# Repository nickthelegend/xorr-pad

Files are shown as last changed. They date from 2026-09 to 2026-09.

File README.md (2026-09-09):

# xorr-pad

**An AI agent that trades on your desk.**

<div align="center">
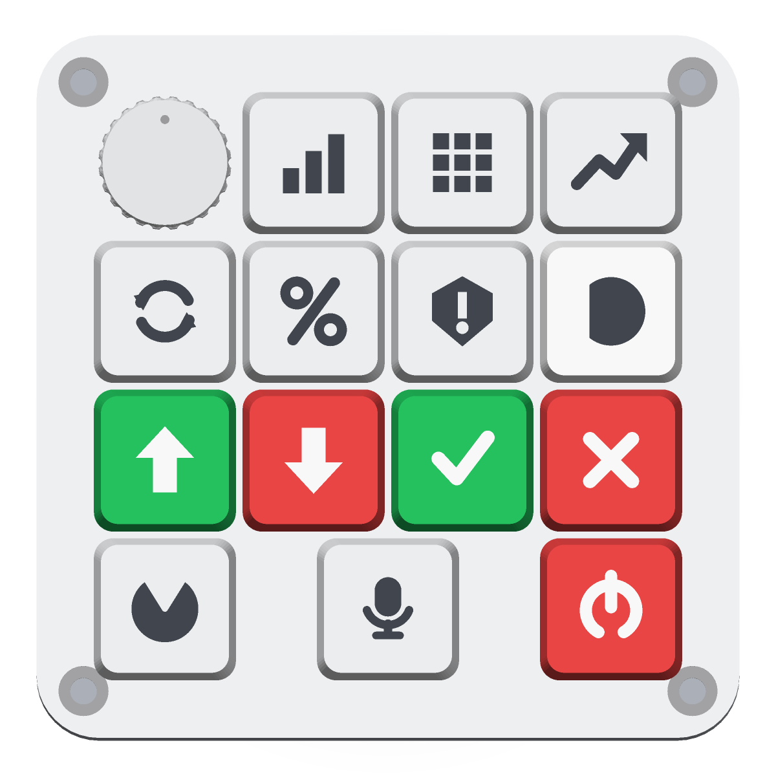
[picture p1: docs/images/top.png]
The xorr-pad deck — six agents, buy/sell, yes/no, Base, mic and a kill key

</div>

A physical deck that runs an autonomous agent on **Base**, and **remembers** —
your risk limits, the positions you hold, and every rule it learned from your
yes/no — through [Sibyl Memory](https://github.com/Sibyl-Labs/Sibyl-Memory).

It trades **four asset classes on Base**, and the strategies it runs are ported
from [xorr](https://github.com/nickthelegend/xorr)'s measured-edge book — built
from forward returns measured on both halves of two years, not from a thesis.

Delete the memory and it trades blind. That is not a slogan; it is
[a test](desktop/test/loadbearing.test.mjs) that runs the same signals with and
without the store and asserts the verdicts diverge.

## What it trades

Every market was picked by measurement, not by taste: quote a real Uniswap V3
pool at $50 and at $500 and compare the two prices. If the bigger order does not
price within 2% of the smaller one, it is not tradeable and it is not listed.

| market | class | pool | a $500 order moves it |
|---|---|---|---|
| **ETH** | crypto | 0.01% tier | 0.01% |
| **cbBTC** | crypto | 0.05% | 0.00% |
| **EURC** | **forex** — a real EUR/USD position on Base | 0.05% | 0.01% |
| **AERO** | defi | 0.05% | 0.10% |
| **MORPHO** | defi | 1% | 0.03% |
| **VIRTUAL** | ai agents (Virtuals) | 0.3% | 0.01% |

Delisted by the same measurement: **DEGEN** (a $500 order moves the pool
**239.7%**), BRETT (52%), cbETH (8.3%), and wstETH/WELL/ONDO (no pool at all).
DEGEN was in the pad's allowlist until this check existed — memory says what you
are *allowed* to trade; only the pool says what you can trade without destroying
yourself on the way in. `swap()` refuses before signing when the two disagree.

**On stocks:** this changed under the project. Coinbase put tokenized equities
live natively on Base on **24 August 2026** — each backed 1:1 by a share held at
Alpaca, carrying dividends and voting rights. Ten of them are listed in
[`stocks.mjs`](desktop/main/stocks.mjs), every one verified against real mainnet
by reading `symbol()` and `decimals()` back off the chain, with $599k–$2.23M of
measured depth apiece: NVDAc, GOOGLc, AAPLc, METAc, AMZNc, MSFTc, SNDKc, SPCXc,
TSLAc, MSTRc.

**The pad cannot trade them yet, and says so precisely rather than failing
vaguely.** Two separate reasons, never conflated:

1. They are **B20 tokens — implemented by the Base node, not as EVM bytecode**.
   `eth_getCode` returns a single byte, `0xef`. anvil forks *state*, and there is
   no state here to fork, so on a fork every call to one of these reverts with
   `OpcodeNotFound`. Measured the same day, same address: real mainnet answers
   `symbol() -> "NVDAc"`, the fork throws. **Equities cannot be demonstrated on a
   fork at any block** — they need `CHAIN_MODE=mainnet` and real money.
2. Their depth is on a concentrated-liquidity pool this build cannot route to
   (a custom factory, `0xf8f2…61Ef`, plus Uniswap v4). The Uniswap V3 pair this
   codebase *can* reach holds $11k — too thin to use. That needs an aggregator,
   which is Phase 2 of [`PLAN.md`](PLAN.md).

So EURC remains the non-crypto market that actually fills today. The equities are
listed, priced by the chain, and refused with the reason — which is the honest
state of a market that went live three weeks ago.

## The book — six measured strategies

Ported from xorr's `backend/strategies`, thresholds and holding periods intact:

| strategy | condition | measured (in-sample / held-out) |
|---|---|---|
| `deep_stretch_reversion` | ≥6% below the 50-bar mean | **+2.351% / +1.249%**, t=7.49, n=1353 |
| `oversold_exhaustion` | RSI < 25 | +0.577% / +0.393%, t=3.81, n=1652 |
| `stretch_capitulation` | ≥3% below the mean on 1.8× volume | two measured effects agreeing |
| `stretch_oversold_confluence` | ≥3% below **and** RSI < 32 | the intersection of the two strongest |
| `volume_thrust` | top-decile up move on 2.5× volume | +0.170% / +0.101%, t=1.84, n=1264 |
| `mr_band_fade` | 2σ below a 20-bar mean, in chop only | the ungated control that survived |

Two gates are shared, as in xorr: dip buying is switched **off** entirely while
BTC is below its 200-day mean (measured +0.946%/trade above it, −0.022% below),
and nothing is bought while it is still making lows.

**Not ported on purpose:** the ~45 inherited "fade the liquidation flush"
strategies. xorr's own gauntlet found almost all of them fail out-of-sample, and
shipping known-failing strategies to make a bigger number would be dishonest.

**And the honest part:** none of this has been shown to make money. xorr's live
book was +$4.32 gross and −$23.07 net over its first 30 trades, the entire loss
being fees. These are real, measured, too-small-to-pay-for-execution edges. The
pad runs them because they are real and explainable, not because they print.

## The deck

| | c0 | c1 | c2 | c3 |
|---|---|---|---|---|
| **r0** | 🎛 size knob | DCA | GRID | MOMENTUM |
| **r1** | REBALANCE | YIELD | RISK | ⬜ BASE |
| **r2** | 🟩 BUY | 🟥 SELL | 🟩 YES | 🟥 NO |
| **r3** | PORTFOLIO | 🎤 MIC | | 🟥 KILL |

Press an agent to take the baton, BUY/SELL to propose, YES/NO to answer — and
every yes/no teaches it. Hold MIC on the pad, or press MIC on screen to start
and again to send, and just say *"buy fifty dollars of ETH"*. A spoken order
goes through the same gate as any other: it arrives as a decision waiting on a
✓, never as a fill.

## Run it

```bash
cd desktop && npm install

# 1. a Base mainnet fork — real contracts and liquidity, no real money
npm run fork

# 2. pull the pools and balances into the fork's cache, once (~2 min)
npm run warm

# 3. the desk app (hosts the backend the pad talks to)
CHAIN_MODE=fork PAD_TOKEN=xorrpad-dev npm start
```

Step 2 is not optional theatre. anvil fetches state from the upstream lazily,
the public Base RPC rate-limits hard, and the first read of a pool can take
**55 seconds** — in the middle of a trade, which looks like the app hanging.
Warming pulls it all in once; after that every read is local and answers in
single-digit milliseconds.

It prints the LAN URL to type into the pad's captive portal. Point a browser at
`http://localhost:8080/?token=xorrpad-dev` if you'd rather drive it by hand —
**every pad key is clickable**, which matters because hand-soldered pads have
dead switches.

Prove the memory claim:

```bash
node desktop/test/loadbearing.test.mjs
```

## How a trade happens

```
memory ──▶ market ──▶ six agents ──▶ decide() ──▶ Uniswap on Base ──▶ journal
recall     real        propose        the gate      real signed tx     writeback
```

`decide()` is built only from what Sibyl remembers: it clamps to your cap,
vetoes anything matching a rule you accepted, refuses to sell a position it
cannot see, and subtracts today's spend from the journal.

**On routing, and on 1inch.** Two routers are built. **Uniswap V3** is a direct
`exactInputSingle` and needs nothing but an RPC. **KyberSwap** is a real DEX
aggregator that needs **no API key and no signup** — it splits across venues and
reaches the concentrated-liquidity pools a direct V3 call cannot, which is the
only way this project can price the tokenized equities at all.

Every fill quotes both and takes the better one, keeping the loser's quote on
the fill so the choice is auditable rather than trusted. Measured on real
quotes, KyberSwap led by 0.42% / 0.023% / 0.082% on AERO / ETH / cbBTC. If the
aggregator fails — it refuses some senders, and it quotes live mainnet while a
fork drifts away from it — the fill falls back to the direct pool and *says so*
on the card.

**1inch is not used.** The name covers three things: an aggregator API, a
self-custody wallet app, and a token. None of them are here. There is no 1inch
call in the codebase, no wallet app and no WalletConnect — the agent holds a key
from the environment and signs with viem, because a pad that needs a human to
approve a wallet popup for every fill is not an agent. 1inch's API needs KYC;
KyberSwap did the job without it.

The route a fill reports is read back off the mined receipt's `to`, so it can
never claim a venue it did not use. Setting `ONEINCH_API_KEY` changes nothing,
and the suite asserts that.

## What's in here

| Path | What it is |
|---|---|
| `desktop/memory/sibyl_bridge.py` | the memory, over stdio JSON (Sibyl is Python-only) |
| `desktop/main/memory.mjs` | Node client — `recallBrief()` and the journal |
| `desktop/main/agents.mjs` | dca · grid · momentum · rebalance · yield · risk |
| `desktop/main/decide.mjs` | the gate where memory changes the trade |
| `desktop/main/dex.mjs` | quotes and real swaps on Base |
| `desktop/main/reflect.mjs` | mines your yes/no history into rules you accept |
| `desktop/main/voice.mjs` | Deepgram speech + a brain that has read memory |
| `firmware/` | the ESP32-S3 sketch, and `keytest` for wiring |
| `cad/` | the enclosure, parametric — `python assembly.py` rebuilds every STL |

## Hardware

ESP32-S3, 14 MX switches, INMP441 mic, MAX98357A amp + speaker. Wiring and pin
map in [`firmware/README.md`](firmware/README.md); dimensions in
[`SPEC.md`](SPEC.md). Caps print in three filaments —
`exports/print/xorr-pad-keycaps.3mf` opens straight in Bambu Studio.

`firmware/keytest` maps a hand-soldered matrix for you: it names each key, you
press it, and it prints a paste-ready `KEYMAP` — plus it beeps per key so you
can hear a dead switch.

## Status

- [x] enclosure, caps, 3MF
- [x] Sibyl memory + the load-bearing proof
- [x] Base fork, real Uniswap fills
- [x] six agents, `decide()`, kill switch
- [x] desk app, voice
- [x] firmware rewritten for xorr-pad — compiles for the S3, backend contract
      covered by the suite; **not yet flashed** (no board on this machine)
- [ ] finish the key sweep (one dead switch, row 3 unswept)
- [x] an aggregator route — **KyberSwap**, which needs no API key at all. It
      reaches the concentrated-liquidity venues a direct V3 call cannot, prices
      every tokenized equity, and every fill picks the better of the two routers
      and records the loser's quote
- [ ] trade the equities for real — the route exists; a B20 token cannot exist
      on a fork, so this needs mainnet
- [ ] Virtuals beyond trading VIRTUAL (no agent-registry integration)

MIT. See [`PLAN.md`](PLAN.md) for the full build plan and
[`SUBMISSION.md`](SUBMISSION.md) for the memory writeup.

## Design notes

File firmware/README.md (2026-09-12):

# xorr-pad — firmware

ESP32-S3 firmware for the trading pad. Take a market in hand, propose a trade,
confirm it with a physical ✓ — or hold the mic key and say it out loud. Wi-Fi
and the backend address are set once through a captive portal and remembered in
flash; **no recompile to change networks**.

Sketch: [`orchestrator_pad/orchestrator_pad.ino`](orchestrator_pad/orchestrator_pad.ino).

> **Nothing on this pad can move money on its own.** BUY and SELL raise a
> decision; only ✓ executes it, only while the backend says it is armed, and the
> same gate answers whether the key was pressed here or on screen. The firmware
> holds no opinion about limits, positions or what is armed — it asks.

## What it does

1. **Provision** — first boot (or hold the reset key at power-on) raises an
   access point, **`xorr-pad-setup`**. Join it; a captive page lists nearby
   networks and asks for the **backend URL** and a **pad token**. The URL is
   validated before it is saved — a pad that cheerfully stores `192.168.1.5`
   with no scheme boots into a state where nothing works and the portal has
   already closed.
2. **Connect** — it starts a telnet console, polls `GET /pad`, and speaks
   something true through the amp: whether it is armed, what is in hand, and
   whether the store has been wiped.
3. **Run** — keys drive the same backend the desk app drives. The status light
   is the backend's state, not the firmware's guess.

## The deck

```
  MOMENTUM   RISK       YIELD      DCA          ← who holds the baton
  ETH        cbBTC      AERO       VIRTUAL      ← what is in hand
  BUY        SELL       SCAN       PORTFOLIO    ← propose / run the book
  ✓ CONFIRM  ✗ REFUSE   MIC        KILL         ← answer / speak / stop
```

Every id is exactly what `POST /key` accepts. There is no translation table: if
an id is not real, the backend says so and the pad speaks the refusal.

**KILL is held, not tapped** — 600 ms. A brush against the key that stops all
trading is not acceptable.

**MIC is hold-to-talk.** The recording goes to `POST /voice` as raw 16 kHz mono
PCM; the spoken reply streams straight back to the amp. A spoken order lands as
a decision waiting on a ✓, exactly like a key press.

## The status light

| State | Light |
|---|---|
| Backend unreachable | dark blue, pulsing — the pad is alone |
| Trading stopped | hard red, steady |
| A decision waits on a ✓ | amber, breathing |
| Memory wiped | white, breathing — it will refuse anything but the smallest trade |
| Armed | the agent's own colour, dim and steady |

The order matters: the most dangerous state wins the light.

## Hardware & wiring

ESP32-S3-DevKitC-1 (**N16R8** — 16 MB flash / 8 MB PSRAM). No pot, no diodes.

<div align="center">
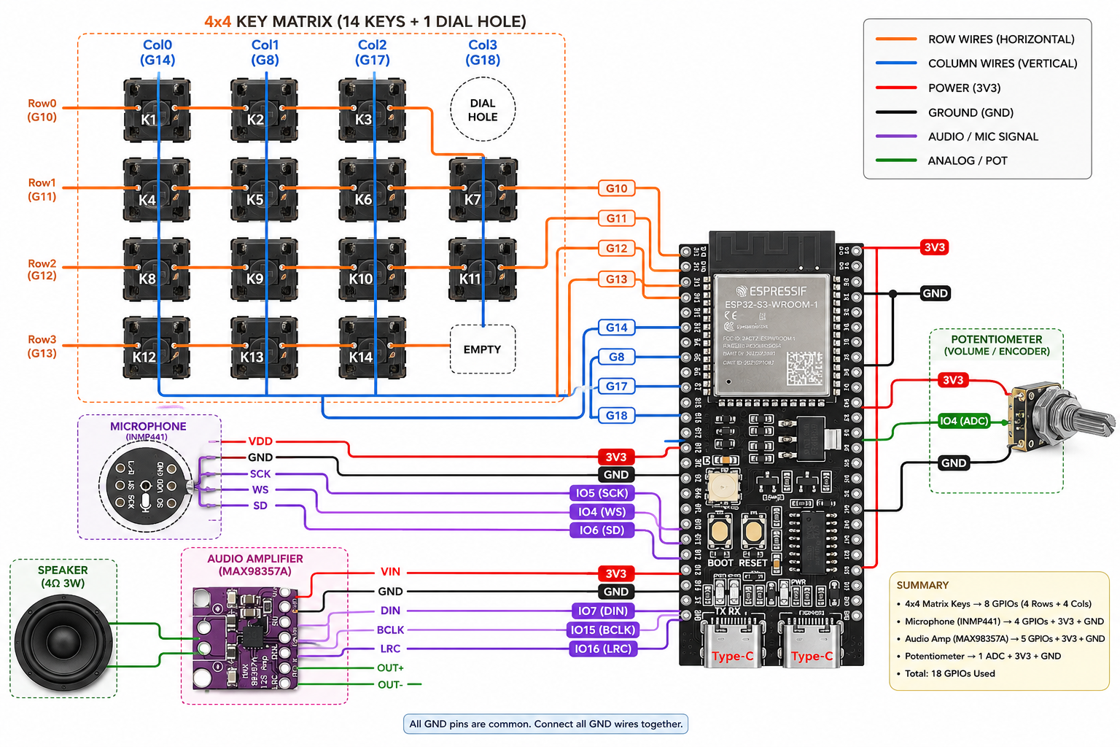
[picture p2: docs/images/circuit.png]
xorr-pad wiring diagram — 4×4 key matrix, INMP441 mic, MAX98357A amp + speaker, on an ESP32-S3-WROOM-1

</div>

The full wiring at a glance: the 4×4 matrix (rows `G10–G13`, columns
`G14/G8/G17/G18`) and the INMP441 mic and MAX98357A amp on I2S. The tables below
are the same thing, cell by cell — all grounds are common.

**Mic — INMP441 (I2S RX):** `VDD→3V3`, `GND→GND`, `L/R→GND`

| INMP441 | SCK | WS | SD |
|---|---|---|---|
| GPIO | **5** | **4** | **6** |

**Amp — MAX98357A (I2S TX):** `Vin→3V3`, `GND→GND`, `SD→3V3` (leave SD high to enable)

| MAX98357A | BCLK | LRC | DIN |
|---|---|---|---|
| GPIO | **15** | **16** | **7** |

**4×4 key matrix** (rows are `INPUT_PULLUP`, columns driven low one at a time —
no diodes needed):

| | Col0 | Col1 | Col2 | Col3 |
|---|---|---|---|---|
| **Rows →** | GPIO 14 | GPIO 8 | GPIO 17 | GPIO 18 |
| Row0 · GPIO 10 | **K1 mic** | K2 | K3 | — |
| Row1 · GPIO 11 | K4 | K5 | K6 | K7 |
| Row2 · GPIO 12 | K8 | K9 | K10 | K11 |
| Row3 · GPIO 13 | K12 | K13 | K14 | — |

**Status LED:** onboard WS2812 on **GPIO 48**.

**Display pod (optional):** a 2.8" ILI9341 320×240 SPI screen (LCDwiki MSP2807),
laid landscape, showing the market in hand — price, 24h move and a 48-hour chart
from `GET /pad/chart`. The enclosure is `exports/display-pod-28.stl` and
`exports/display-cap-28.stl` (`cad/part_display.py`); the print plate is
`exports/print/display-plate-28.3mf`. Touch is not used.

| Module pin | VCC | GND | CS | RESET | DC | SDI(MOSI) | SCK | LED |
|---|---|---|---|---|---|---|---|---|
| Goes to | 3V3 | GND | GPIO **1** | GPIO **42** | GPIO **41** | GPIO **40** | GPIO **39** | GPIO **2** |

Leave SDO(MISO) and the five touch pins (T_CLK, T_CS, T_DIN, T_DO, T_IRQ)
unconnected. At power-on the screen shows a test card — colour bars and an arrow
that should point up the slant. If it points down, type `rot 3` on the telnet
console to check, then set `TFT_ROTATION 3` in `config.h`; `screen` reports what
the display last drew. These pins avoid the octal PSRAM (35–37), USB (19/20),
UART0 (43/44) and the strapping pins (0, 3, 45, 46).

**2.4" UNO shield:** the pod fits it (`exports/display-pod-24.stl`), but this
firmware does not drive it. That shield is an **8-bit parallel** display — 12
pins for the LCD alone, and its resistive touch shares four of them — while the
pad's ESP32-S3 has 10 free. The SPI version of the same 2.4" ILI9341 panel (with
XPT2046 touch) fits the pin budget; the pod is parametric (`MODULES` in
`cad/part_display.py`), so another board is a few numbers.

All pins live in [`orchestrator_pad/config.h`](orchestrator_pad/config.h) — change
them there if your wiring differs.

The 12-second record buffer is 384 KB and **lives in PSRAM**, so PSRAM must be
enabled at build time. It is off in the default board config.

## Building

### From the command line

```bash
arduino-cli core install esp32:esp32
arduino-cli lib install WiFiManager
arduino-cli lib install "Adafruit ILI9341"

arduino-cli compile \
  --fqbn esp32:esp32:esp32s3:FlashSize=16M,PartitionScheme=app3M_fat9M_16MB,PSRAM=opi \
  firmware/orchestrator_pad
```

**Those board options are not optional.** With the bare `esp32:esp32:esp32s3`
default you get a 4 MB partition scheme — the binary lands at 90% of the
available app space — and **PSRAM disabled**, which means the record buffer
never allocates. With the options above it is 39% and the mic works.

To flash, add `--port <the pad's port>` and `upload` in place of `compile` —
`/dev/cu.usbserial-*` on the board's UART USB-C, where the Serial log also
comes out. Plugged into its native USB-C instead (`/dev/cu.usbmodem*`), add
`,CDCOnBoot=cdc` to the FQBN to get the log there. With more than one ESP32
connected, check the port is the pad's before uploading.

### From the Arduino IDE

**Libraries** (Library Manager):

- **WiFiManager** by *tzapu* — the captive portal.
- **Adafruit ILI9341** (pulls in Adafruit GFX) — the display pod.
- `ESP_I2S`, `WiFi`, `HTTPClient`, `Preferences` ship with the **arduino-esp32
  core 3.x** — nothing to install, but you do need core 3.x (Boards Manager →
  "esp32" by Espressif, ≥ 3.0).

**Board settings** (Tools menu) — the three starred ones are the same
constraints as the FQBN above:

- Board: **ESP32S3 Dev Module**
- ⭐ **PSRAM: `OPI PSRAM`** — the record buffer is `ps_malloc`'d; without this it
  fails to allocate and the mic won't record.
- ⭐ **USB CDC On Boot: `Enabled`** — so the Serial monitor works over USB-C.
- ⭐ **Partition Scheme: `Huge APP (3MB No OTA/1MB SPIFFS)`** — the TLS stack
  pushes the build to ~90 % of the *default* app partition (it fits, but
  barely). Huge APP drops it to ~38 %. Flash Size: `16MB`.

**Steps:**

1. Open [`orchestrator_pad/orchestrator_pad.ino`](orchestrator_pad/orchestrator_pad.ino).
2. Install WiFiManager, set the board options above, pick the port, **Upload**.
3. First boot: join the **`xorr-pad-setup`** Wi-Fi from your phone. If the portal
   doesn't pop up, browse to `http://192.168.4.1`.
4. Pick your Wi-Fi, enter the **backend URL** and **pad token** (below), save.
5. It joins, says what state the desk is in, and you're ready: **take a market,
   press BUY, confirm with ✓** — or hold **K1** and say it.

### Backend URL & token

One field decides where — and how — the pad reaches the backend; the **scheme
picks the transport**:

| You're… | Enter | Token |
|---|---|---|
| on the same Wi-Fi as the Mac | `http://<mac-lan-ip>:8080` (e.g. `http://192.168.1.20:8080`) | blank is fine on a trusted LAN |
| anywhere / the pad moves around | `https://<machine>.<tailnet>.ts.net` (Tailscale Funnel) | **required** — Funnel is public |

- **`http://…`** → plain connection. Use the Mac's **LAN IP**, *not* its
  `tailscale ip` (`100.x`) — a bare ESP32 can't route to a tailnet address.
- **`https://…ts.net`** → TLS, with the Let's Encrypt root pinned (the pad
  verifies the cert, so the token can't be MITM'd). Set the same `PAD_TOKEN` on
  the backend, which lives in [`desktop/`](../desktop).

A URL that cannot work is refused at the portal rather than saved — see
`Provision::validUrl`. Change either later without reflashing: `reset-wifi` over
telnet (or hold **K1** at power-on) re-opens the portal.

## Telnet console

The S3's USB-CDC serial can be flaky, so the pad mirrors its logs to a telnet
server and takes commands back — no cable needed:

```
telnet <pad-ip>
```

| Command | What it does |
|---|---|
| `status` | Wi-Fi, heap, backend, and the pad's view of the backend |
| `pad` | one raw `GET /pad` poll, printed |
| `map` | the key map as currently compiled |
| `key <id>` | press any key id by hand — the same route the caps use |
| `say <text>` | speak a line through the amp |
| `talk` | hands-free record for 4 s and send |
| `url <u>` / `token <t>` | repoint the backend without re-provisioning Wi-Fi |
| `reset-wifi` | forget the network and reopen the portal |

`say hello` and `talk` are the fastest way to prove the audio path end to end.

## Mapping a scrambled matrix

[`keytest/`](keytest) is a standalone sketch — flash it *instead of* the main
firmware. It has two modes over the serial monitor at 115200 baud:

- **MAP** names a key, you press it, and it records which matrix cell actually
  fired (`s` skips a dead one). At the end it prints a ready-to-paste `KEYMAP`,
  so a scrambled or half-broken wiring job is fixed in software rather than
  re-soldered.
- **DIAG** is free-press: every press prints its cell, and a grid shows which
  cells have ever fired (`*`) versus never (`.`). This is how you find a dead
  switch.

## Troubleshooting

| Symptom | Fix |
|---|---|
| No serial output | Set **USB CDC On Boot: Enabled**, re-upload |
| "PSRAM alloc failed" in the log | Set **PSRAM: OPI PSRAM** (or `PSRAM=opi` in the FQBN) |
| "backend not reachable" | Backend running? Right URL? On `http://`, use the Mac's **LAN IP** not `100.x`. Fix with `url <u>` or `reset-wifi` |
| Works on LAN, fails on the `ts.net` URL | Is `tailscale funnel` running? Does `PAD_TOKEN` match on both sides? (a 401 means the token's wrong/blank) |
| Portal never opens | Forget/rejoin `xorr-pad-setup`, or browse to `192.168.4.1` |
| Portal won't take my URL | It needs a scheme: `http://192.168.1.20:8080`, not `192.168.1.20` |
| Amp silent | Check `DIN/BCLK/LRC` wiring and that the amp's **SD pin is tied to 3V3** |
| Mic captures nothing | Check `SCK/WS/SD`, and tie the INMP441 **L/R pin to GND** |
| Keys wrong / swapped | Flash `keytest`, run MAP mode, paste the map it prints |

## What is verified, and what needs the board

Compiled and tested against the real backend on every run of
[`desktop/test/verify.mjs`](../desktop/test/verify.mjs) section P: the `/pad`
poll, `/speak`, the key ids, and the voice round trip.

The URL validator is unit-tested. The captive-portal markup is checked in a
browser.

**Not verifiable without hardware:** Wi-Fi provisioning on the device, I2S mic
capture, amp playback, matrix scanning, and NVS persistence across a power
cycle. Those are marked untested rather than assumed.

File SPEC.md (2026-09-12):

# xorr-pad — dimensional spec (v8)

Open-source ESP32 macropad that trades on Base. Six strategy agents, six
markets across four asset classes, buy/sell with a physical yes/no gate,
hold-to-talk voice, and a kill switch.

The chassis is unchanged from the v7 LoomPad build — same tray, same plate,
same 19.05 mm grid, same hand-soldered 4x4 matrix. Only the keycaps and the
firmware's key bindings changed when the product did, which is why the
dimensions below still hold.

All dimensions in **mm**. Axes: X right, Y back (away from user), Z up.
Origin: center of the case footprint, Z=0 at the tray's outer bottom face.

## Layout (19.05 mm grid, 4 columns x 4 rows)

Column centers X: -28.575, -9.525, +9.525, +28.575 (cols 0..3)
Row centers Y: +28.575, +9.525, -9.525, -28.575 (rows 0..3, row 0 = back/top)

The physical grid is 4x4. One cell is the knob, leaving 14 switch positions;
the v7 2u voice bar is now a 1u MIC cap centred at X=0, so every cap is 1u.
This table is generated from `cad/partlib.py: key_layout()` — if they disagree,
the code is right.

| Pos | What | Cap colour | Glyph (debossed) |
|---|---|---|---|
| r0c0 | **mock knob** — snap-fit, spins, no encoder (see below) | off-white | knurled, tick dot |
| r0c1..c3 | strategy agents: DCA, GRID, MOMENTUM | white | `dca`, `grid`, `momentum` |
| r1c0..c2 | strategy agents: REBALANCE, YIELD, RISK | white | `rebalance`, `yield`, `risk` |
| r1c3 | **BASE** — runs the strategy book across every market | plain white | `base` |
| r2c0 | BUY | green | `buy` |
| r2c1 | SELL | red | `sell` |
| r2c2 | YES — confirm the pending trade | green | `check` |
| r2c3 | NO — refuse it | red | `cross` |
| r3c0 | PORTFOLIO | white | `portfolio` |
| r3, centred at X=0 | MIC (hold-to-talk), 1u cap on the old 2u switch | white | `mic` |
| r3c3 | KILL — disarm everything | red | `kill` |

Total: **14 MX switches** (all 1u caps) + 1 mock knob. One grid cell (r3c2) has
no cap: the mic sits centred between c1 and c2.

**The desk app's deck has 15 keys, the pad has 14.** The extra one is SCAN, and
it has no switch — the BASE key runs the same book, so nothing is unreachable
from the hardware, but SCAN itself is desk-only. The pad also has no market
keys: which of the six markets is in hand is chosen in the desk app.

**The knob has no encoder.** This build ships a snap-fit knob that spins freely
in the plate hole: there is no EC11, so it sends nothing. Trade size is set in
the desk app. `cad/part_knob.py` builds the mock part and `cad/audit_fit.py`
asserts it clips and spins.

**Cap colours are filament, not decoration.** Green (#22C55E) and red (#EF4444)
are the two coloured spools; every other cap is white. The desk app's palette
is taken from these values, not the other way round.

## Case (two printed shells + knob + caps)

### Tray (bottom shell) — `part_tray.py`
- Outer: 90.0 x 90.0, corner R8, height **40.0** (v7 fat/tall base — +12 over
  v6's 28.0, for lots of open headroom above the board; the interior is a
  component bay). Wall 2.4, floor 2.4.
- Ledge for the top's skirt: below Z=33.5 wall is 2.4 thick; above Z=33.5 the
  inner face steps out so wall is **1.2** thick (skirt seat).
- 4 corner bosses Ø7.0 at (±39, ±39) — **round** (M3 heat-set inserts thread
  in): solid pedestal from floor top (Z2.4) to **Z=31.5**, insert ring
  Ø7.0/Ø4.0 to **Z=37.5** (bore 6.0 deep from the top, floor at Z 31.5 — M3
  heat-set insert). The bosses now run floor→37.5 (through the raised ledge).
- **USB windows**, BOTH side walls (X=+45 and X=-45): each **26.0 wide** in
  Y centered Y=0, **Z 17.0..23.5**, through BOTH wall columns. The board
  turns 90° so its ports face a side wall, and the bay is **reversible** —
  the board installs **ports-right or ports-left**, and the *unused* window
  is documented as a **wire pass-through** (run the speaker/mic/amp harness
  or a USB extension out of it). The board's dual side-by-side USB-C ports
  sit on its TOP face (shells 8.94 x 3.3 → Z 17.6..20.9, center 19.25) and
  exit through whichever window they face; each window is wide + tall enough
  that exact port offsets don't matter (shells stay inside for port centers
  |y| ≤ 8.53, a 12-wide plug hood for |y| ≤ 7.0), and the receptacle face
  sits only ~1.7 behind the outer wall — under the ~2.5 of exposed plug
  shroud, so any hood works at the aperture mouth. v7 raised the ledge to
  33.5, so each window top (23.5) now sits **entirely below the ledge** —
  both wall columns close the window with a solid cap at 23.5 and run solid
  to their tops (liner→33.5, outer→40.0), and the **plate skirt no longer
  needs a USB notch**. The two side cuts split each cut wall band into a back
  arc and a front arc — every piece is still its own watertight prism, fused
  to the solid ring bands above and below by the 0.2 lap.
- **Board bay (rotated + REVERSIBLE)** — dual-USB-C ESP32-S3 clone,
  components UP, factory header pins DOWN, laid **along X**: up to **64.0
  long (X) x 30.0 wide (Y)**, centered Y=0 (|y| ≤ 15). Two installs, both
  seating identically because every bay feature is mirror-symmetric about
  X=0:
  - **ports-right** X **-22.0 … +42.0** (USB-C exits the X=+45 window)
  - **ports-left**  X **-42.0 … +22.0** (USB-C exits the X=-45 window)
  - side shelves (BOTH walls): tabs protruding 1.6 from each side wall's
    inner face (42.6), spanning **|x| 41.0..42.8** (0.2 lap into the liner)
    and **|y| ≤ 14.0**, body Z 13.5..16.0 — the board's port edge seats on
    one and its far edge overhangs the other; **Z=16.0** top faces (1.0
    bearing, 0.6 edge-to-wall gap on the port side).
  - mid-span ribs: two walls at **X +4.0..+7.0** and **X -7.0..-4.0**,
    **Y +1.0..+16.0**, floor to **Z=16.0** — they carry the board's middle
    (~112 mm² of total seat bearing per orientation). They stay at Y ≥ +1.0
    on purpose: the speaker flange occupies X ±36, Y -42..0, and a rib
    crossing it would foul the flange (1.0 clear as drawn).
  - **board cage (FLAT — NO cylindrical posts, v7)**: the board is caged in
    Y by flat guide walls only, placed only in speaker-clear zones (the
    flange is X ±36, Y -42..0; supports live at Y>0 or |X|>36). Inner faces
    at |y| = 15.1 → 0.1 clearance per side to a 30-wide board, tops **Z=19.0**
    (1.4 lip over the board top at 17.6). Mirror-symmetric about X=0:
    - **back guide rail**: a flat wall, inner face **Y=+15.1**, outer
      **Y=+17.1** (2.0 thick), spanning **X -10.0..+10.0**, floor→Z=19.0 —
      caps the board's +Y edge. (Nominal span was X ±34, but the amp
      L-ridges reach X 10.5 inside the rail's Y band 15.1..17.1, so the rail
      is trimmed to **±10.0** to clear the amp by 0.5 while staying
      symmetric and watertight; it fuses with the two mid-span ribs at
      Y 15.1..16 by design, tying it to the load-bearing ribs.)
    - **front corner tabs**: two flat tabs, inner face **Y=-15.1**, outer
      **Y=-17.1**, spanning **X 36.8..40.0** and **X -40.0..-36.8** (both at
      |X|>36, clear of the flange edge at 36 by 0.8), floor→Z=19.0 — they
      guide the board's front-edge corners in whichever orientation reaches
      that side.
    Together with the flat mid-span ribs and dual side shelves (all
    retained, unchanged), the board is caged in Y from both edges while
    nothing ever crosses the speaker flange.
  - under-board clearance floor→16.0 = **13.6 mm** for the soldered header
    pins (~8.5 under the PCB) + angled dupont connectors. Headers now run
    along the board's long edges (y = ±15). Wire in the open pockets either
    side of the ribs. Pin tails that land over a rib (X ±4..7, Y +1..+16)
    must be clipped flush; over the speaker zone (Y < 0) the driver bump can
    rise to Z 14.9 under the pin rows — clip there too, or verify your
    speaker's bump footprint. (Headers usually stop ~2 mm short of the
    board ends, clearing the 1.0 shelf lip.)
- **Speaker bay** (down-firing, flange ON the floor, centered (0, -21)):
  - floor opening: racetrack (rounded-rect R12) **54 x 24** at (0, -21) with
    two 2.0-wide grille bars along X → 3 slots (~6.7 each), through both
    floor layers.
  - 4 screw pilots Ø2.4 THROUGH the floor at (±31.5, -37.5) and
    (±31.5, -4.5) — the 63 x 33 pattern. M2.5 x 6 self-tappers from inside:
    heads on the flange, tips end 2.1 under the floor, inside the ≥3 mm
    foot gap. The two back pilots' bottom rims merge ~1.0 into the front
    feet-recess rims (0.6 recess layer only) — stick those feet biased
    outward.
  - fits flanges up to **72 x 42** (a sharp-cornered 72 x 42 grazes the two
    front bosses by ~0.5; real cavity flanges with corner R ≥ 6.5 clear —
    **measure yours**) and driver bumps up to **Ø50 x 11 tall** (oval, ≤
    50 x 40 in plan): bump top 2.4 + 1.5 + 11 = **14.9** clears the board
    underside at 16.0 by 1.1. **Measure the bump height — the bay assumes
    ≤ 11.**
- **Amp pocket**: four L-corner ridges (1.5 wide, 2.0 tall, 6-long legs)
  framing a 20 x 20 pocket centered **(+22, +27)** — the MAX98357A drops in,
  foam-tape mounted. It sits on the back strip, out from under the rotated
  board: the ridges span X 10.5..33.5, Y 15.5..38.5, so the outer edge clears
  the board edge at Y 15.0 by **0.5** (both orientations), the corner bosses'
  inner face at X 35.5 by **2.0**, and the speaker by 15.5. v7 deleted the
  locator posts, so the pocket is now a **clean, full 20 x 20** (the old
  (+20, +17.6) post no longer clips its south edge); an ~18 x 16 breakout
  drops in with ~1.0/side play. The nearest cage wall is the back rail,
  trimmed to ±10 so it clears the amp by 0.5.
- **Wire bar** (FLAT — replaces the v6 wire posts, NO cylinders): a low flat
  wall along the west interior, inner face **X=-36.0**, outer **X=-38.0**
  (2.0 thick), spanning **Y +6.0..+30.0**, floor→**Z=8.0**, with **two
  3.2-wide x 2.0-tall through-slots** (band-split in Z, at Z 3.0..5.0)
  centered **Y=+12** and **Y=+24**. A zip tie threads a slot and cinches the
  harness against the bar. It tops out at Z 8.0 — well below the left USB
  window (Z 17.0) — and Y 6..30 clears the speaker flange (Y≤0) by 6.0 and
  the (-39, +39) corner boss by 5.5. It underlies the ports-left board
  footprint in plan but sits 8.0 below the board underside (16.0), so it
  never obstructs board seating in either orientation.
- **Mic grille**, front wall (Y=-45): 3 x 1.5 square ports, spacing 3.0,
  centered X=-20, **Z 19.4..20.9** — far below the raised 33.5 ledge; the round
  I2S mic module glues behind them, above the speaker body. (Replaces v3's
  low-Z round ports.)
- Feet recesses: bottom face, 4 x Ø9.0 x 0.6 deep at (±36, ±36). Use
  **≥3 mm tall feet** so the down-firing speaker breathes (and the M2.5
  tips stay 0.3 off the desk).

### Top plate — `part_plate.py`
- Plate: 90.0 x 90.0, R8, **1.5 thick**, spans Z 40.0 → 41.5 (counterbore
  bands 40.0..40.7 + 40.5..41.5; case stack ~41.5 mm + caps/knob).
- 14 MX cutouts **14.1 x 14.1** (14.0 nominal + 0.1 print tolerance) at the
  grid positions above (2u voice = one switch centered at X=0, r3). These
  are exactly donor-keyboard-style plate holes — harvested 3-pin white MX
  clones clip straight into the 1.5 plate.
- **Switch sockets + deck (v5.1, donor-board style, print-clean)**: under
  every cutout a pocket box cages the switch body — walls 1.6 (outer 17.3
  sq) from **Z 36.5** (the MX base-seat plane, plate top − 5.0) up 0.2 into
  the plate. Flipped for printing, the plate is pure vertical walls: no
  bridges, no floating regions, no supports. The footprint floor is the
  separate **switch deck**: a 1.2-thick flat sheet (78 × 78 R6, Z
  35.3..36.5) carrying all 14 MX clusters — center post Ø**4.15** (snug on
  the Ø4.0 post), contact pin holes Ø**2.0** at (−3.81, +2.54) and
  (+2.54, +5.08), 5-pin leg holes Ø**1.85** (snug on Ø1.7) at (±5.08, 0);
  offsets from each key center, +Y toward the back. It prints FLAT
  (perfect holes), presses onto the switch posts/legs from below
  (friction-fit), seats against the socket-wall rims, has a 16 sq cutout
  under the EC11 body and Ø8.8 notches at the four screw towers (≥0.15,
  audited). The metal pins protrude **2.1** below the deck (tips Z 33.2):
  solder the matrix wires directly to them, PCB-style.
- Knob hole Ø**7.4** at r0c0 (EC11 M7 threaded bush).
- Skirt: ring 1.15 thick x 6.7 deep (Z 33.5 → 40.2), outer profile =
  87.3 x 87.3 R6.9 x-y, inner 85.0 x 85.0 R6.3 (drops inside the tray's
  87.6 upper 1.2 wall with ~0.15 clearance per side). Notched ONLY for the
  bosses now: **Ø8.6 corner clearances** at (±39, ±39) around the tray
  bosses (which rise to Z 37.5, through the skirt band). v7 raised the ledge
  to 33.5 while the USB windows still top out at 23.5 — the **side windows
  sit entirely below the ledge**, no longer cross into the skirt seat, so the
  **v6 side USB notches are gone**. The ring survives as **4 arc segments**
  (one per edge, severed at the 4 corner notches), each a watertight prism
  fused to plate band A. (The front mic notch is likewise unneeded: the mic
  grille at Z 19.4..20.9 sits far below the ledge.)
- 4 screw towers Ø7.6 from Z 37.5 → 40.2 at (±39, ±39), through-hole Ø3.4
  continuing through the plate, counterbore Ø6.4 x 0.8 from the top face
  (M3 x 8 button-head into the tray inserts).

### Keycaps — `part_caps.py`
- 1u: base 18.2 x 18.2 R2.5, top 16.4 x 16.4 R2.2, height **7.5** (loft taper),
  wall 1.6, hollow underneath.
- 2u voice bar: base 37.25 x 18.2, top 35.4 x 16.4, same height/wall.
- MX stem: post Ø5.8, length 3.9 below the cap ceiling; cross slots
  4.15 x 1.35, depth 3.9 (friction fit on MX stem).
- Glyphs debossed **0.6** into the top: build the top 0.8 mm of the cap as a
  layer with glyph-shaped holes; solid body below ends 0.6 lower, glyph
  islands (e.g. the pixel-pal's eyes) overlap 0.2 into the body below so every
  shell fuses when sliced.
- **Legend infills**: each glyph also exports as a separate flush 0.6 prism
  (`<id>-legend` items, merged into `exports/legends-all.stl`, same drop as
  `caps-all.stl` so both stay aligned). Print caps + legends together in two
  colors (AMS/MMU, or a manual filament swap on the last 3 layers when caps
  print top-face-down), or skip the file and paint-fill the recesses. Legend
  colors per key live in `partlib.key_layout()` (white on colored caps, dark
  gray on white caps).
- **One-filament reprint** (`export_caps_plate.py` →
  `exports/print/caps-plate.3mf`): every cap but MIC, no legend infills.
  Symbols use the `outline` style — a bold mark (BUY, SELL, BASE, RISK,
  PORTFOLIO) is cut as a **0.9 outline** with its middle left standing; a mark
  under ~2.4 across (DCA, GRID, MOMENTUM, REBALANCE, YIELD, YES, NO, KILL) is
  cut as a single line, and so is any middle under 3 mm² (the dot an X would
  keep where its strokes cross). Caps lie **upside down on their top faces**,
  stems up, where they sit on the pad, 26 apart. No cut is wider than 2.6
  (every ceiling a short bridge), no groove pinches under 0.8, no wall under
  0.6 stands between cuts, and the wall leans out 7.4° — so the plate prints
  **with no supports**. RISK's bar stops 0.9 above its dot and YIELD's rings sit 0.75 off
  the slash, so those gaps print.

### Knob — `part_knob.py` (v7.1 MOCK, no potentiometer)
- Ø17.0, height 15.0. Knurl: 24 flutes (Ø1.6 scallops on the rim).
- Top: 1.5 chamfer loft to Ø16.0, tick-dot deboss near edge.
- **Snap-fit peg** on the underside — no EC11 shaft: a Ø**7.2** tube split by
  1.2-wide cross-slots into 4 flex fingers, hollow Ø4.6 core, with a Ø**8.2**
  barb at the tip and a stepped lead-in chamfer. Push it through the plate's
  Ø7.4 hole: the fingers compress, the barb springs out under the plate. The
  knob body rests on the plate top (Z 41.5) and the barb catches the
  underside (ledge Z 39.8, **0.2 axial play** below the plate bottom) so it
  stays on **and spins freely** — a display dial for the demo. The plate is
  identical to an EC11 build; only this part differs. **Tuning:** if the snap
  is too tight, drop `BARB_D` to 8.0; too loose, raise to 8.4.
- Prints **crown-DOWN** (peg pointing up) — no supports.

## Assembly (`assembly.py`)
- Tray at Z0 → plate on top (plate top face Z=41.5).
- Caps: bottom face at **Z=47.0** (switch seated, cap floats ~5.5 over plate).
- Knob: bottom at **Z=41.5** over r0c0 (rests on the plate top; snap peg
  clips through the Ø7.4 hole and spins).
- Exports: `exports/orchestrator-pad-assembled.glb`, `exports/orchestrator-pad-exploded.glb`
  (tray +0 / plate +20 / caps +40 / knob +52), plus one STL per printable part
  (`tray`, `plate`, `caps-all`, `legends-all`, `knob`).

## Colors (GLB preview only)
tray `#AEB4BC`, plate `#F4F5F7`, preset cap `#D8DCE2`, Grok `#141414`,
Codex `#6366F1`, Claude Code `#D97757`, Antigravity `#2D6BFF`,
opencode `#FAFAF8`, Kiro `#7A3FF2`, Cursor `#26282E`,
run/approve/reject/prompt/send `#FFFFFF`, voice bar `#FFFFFF`, knob `#E8E9EB`.
Legends: white `#FFFFFF` on colored caps, dark `#3F444D` on white caps,
mid `#8A919E` on the preset.

Logo glyphs (`grok`, `codex`, `claude`, `antigravity`, `opencode`, `kiro`,
`cursor`) are simplified geometric homages debossed 0.6 into the caps; the
original marks belong to their respective projects.

## BOM (v7)
Dual-USB-C ESP32-S3 clone board **with factory pin headers** (pins DOWN,
components + USB-C on TOP — the 13.6 under-board bay swallows the ~8.5 pin
tails; v3's headerless rule is gone). **Fit it sideways**: the board lies
along X with its ports facing a side wall, and you choose **ports-right or
ports-left** at assembly time — the bay is symmetric, so both drop in the
same way. Also: MAX98357A I2S amp breakout, 4Ω 3W
cavity speaker (flange ≤ 72 x 42, driver bump ≤ 11 tall — **measure it**)
+ 4 x **M2.5x6** self-tappers, round I2S mic module (INMP441-class),
**no potentiometer** (this build is hold-to-talk; the knob is a mock display
dial that snaps into the plate — omit the EC11), 14 x MX-style switches (donor-harvested
3-pin white MX clones fine), 4 x M3 heat-set inserts + **M3x8** button-head
screws (unchanged in v7: head bears at Z 40.7 under the counterbore, tip at
Z 32.7 vs the bore floor 31.5 — margin **+1.2**, and it still reaches the
insert zone; an M3x10 would bottom out in the Ø4.0 x 6.0 boss bore 0.8
before the head clamps), 4 x rubber feet Ø8 **≥3 mm tall** (down-firing
speaker + screw-tip clearance), zip ties for the wire bar, jumper wires.
Optional: WS2812 under the preset keys.

## Print notes
0.4 nozzle, 0.2 layers, PETG or PLA. Tray + plate flat side down, no
supports (the **two** 26 mm bridges over the side USB windows and the
**two** 1.6 shelf tabs print unsupported; the mid-span ribs, the flat board
cage — back rail + 2 front tabs — and the flat wire bar are all plain walls
off the floor). Caps upside down (top face on bed) or with tree supports;
**knob crown-down** (snap peg pointing up, prints support-free). Case is
~41.5 tall; with caps ≈ 54.5 overall (knob crown at
57.5). Every part = union of closed shells; slicers merge
coplanar/overlapping shells.

## Display pods — `part_display.py`

Slanted stands that sit directly behind the pad and key onto it. One profile,
one pod per screen: each entry in `MODULES` gets its own pod and coupon, and
`cad/audit_display.py` checks every one.

Shared by every pod:
- **90.0 W**, the pad's own width. Back corners R8 in plan; the lower front
  wraps the tray's R8 back corners up to the plate top, 0.2 off the case.
- Keyed by a **1.6 lip resting on the plate top (Z 41.5)**, Y 39.0..45.2,
  **|X| ≤ 35.0** — 1.3 behind the back-row caps, 1.9 behind the knob, 1.15
  clear of the M3 button heads. No part of the pad changes.
- The window is **centred on the pad** wherever the PCB has room to slide:
  where a module's active area sits off its PCB centre, the PCB pocket moves
  instead. A PCB that fills the pod's width (the 2.8") stays centred, and its
  window follows the active area. The window's outer 1.2 is bevelled 45°,
  leaving a 0.8 land.
- 2.0 walls and bezel — the 2.8" thins its side walls to 1.6 to take an 86 PCB;
  2.0 side rails and end stops locate the PCB, taped in through the back.
- **Cap**: the back of the pod is a separate part cut from the same outline —
  the body's last 8.0, rounded R8 corners and all — so closed up the two read as
  one piece with a single 0.15 seam. Tongues on the cap (1.2 thick, 6.0 long)
  slide inside the body's floor, roof and both side walls, so the seam is a lap
  with no line of sight through it; **4 × M2.5 × 6
  self-tappers** — the speaker's hardware — pass through the cap's back into
  square-pilot bosses rooted in the body, top and bottom at X ±35.5. Each pod is
  made deep enough that its headers and their connectors end 1.0 in front of the
  cap's back wall and clear of the bosses and tongues; a side tongue steps around
  a header row standing at its wall (the 2.8").
- **Cable opening**: a 14 × 8 R3 slot in the **right side wall**, 5.0..19.0
  behind the pod's front face at **Z 16.25..24.25** — level with the pad's own
  side USB windows (Z 17.0..23.5), so the cable runs straight along the tray into
  one.
- Four **10 × 10 × 0.6 recesses** under the base for stick-on rubber feet.
- **Printing**: the body stands **upright on its floor** and the cap lies on its
  back, both with **tree supports** set per object. Upright, only the roof behind
  the face, the top bosses and the lip hang over air, and the body's supports
  come out through its open back. Lying on a side wall — the old orientation —
  the whole upper side wall hung over the cavity, which Bambu Studio flags as a
  floating cantilever.
- **One plate**: `exports/print/display-plate*.3mf` (Bambu Studio: two named
  objects on filament 1, each mesh about its own centre and placed by its build
  item, each with its supports; the AMS slot is picked when the job is sent) and
  `exports/display-plate*.stl` lay the cap **20 to the body's left**. The body's
  tree supports reach ~16 behind it and ~9 past its right wall; with the cap 10
  behind the body, Bambu Studio refused the plate for G-code path conflicts.
  200 wide, for a 256 bed (P1S/X1). `cad/slice_bambu.py` slices a plate for a
  P1S 0.4 on the Textured PEI plate into `display-plate*.gcode.3mf` and fails
  unless the result reads like a P1S job.

| | 1.54" ST7789 (SPI) | 2.4" ILI9341 UNO shield | 2.8" ILI9341 SPI (MSP2807) |
|---|---|---|---|
| Exports | `display-pod.stl`, `display-cap.stl`, `display-coupon.stl` | `display-pod-24.stl`, `display-cap-24.stl`, `display-coupon-24.stl` | `display-pod-28.stl`, `display-cap-28.stl`, `display-coupon-28.stl` |
| PCB | 44 × 32 (listed) | 72.20 × 52.7 (listed) | 86.0 × 50.0 (LCDwiki outline drawing) |
| Active area | 27.72 × 27.72 | 48.96 × 36.72 | 57.6 × 43.2 |
| Glass front to PCB back | 4.0 | 6.6 (panel + touch **estimated**) | 5.6 (drawing) |
| AA offset from PCB centre | 3.0 along the slant | 3.6 across, away from the reset button (**from a photo**) | 4.9 across, toward the SD end (drawing): the window sits 4.9 left of centre |
| Window | 28.9 × 28.9 | 52.6 × 40.3 | 60.8 × 46.4 — the bezel lands 0.6 outside the touch film's 59.45 × 45.2 viewing area |
| Face | 52.6 at 55° | 61.3 at 50° — it gets touched | 58.6 at 50° |
| Pod W × D × H | 90 × 56.4 × 89.1 | 90 × 72.0 × 93.0 | 90 × 63.4 × 90.9 |
| Room behind the PCB | 10 | 25 (headers + dupont housings) | 22: the 14-pin header stands on the right short edge, beside the cable opening |

**Measure your module and print its coupon before the pod.**

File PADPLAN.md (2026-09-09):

# PADPLAN.md — the physical pad, end to end

> **This is the record of the firmware rewrite, not a live status.** Its backend
> contract (section A) is now covered by `desktop/test/verify.mjs` section P,
> which runs on every pass; its hardware items (section D) are still untested
> because no board has been attached. `PLAN.md` Phase 2 carries the current
> status.

The desk app is only half the product. The other half is a real ESP32-S3 macropad
on the desk that provisions its own Wi-Fi, finds the xorr-pad backend, and drives
the same gated trading loop by hand and by voice.

This plan is written **before** any of it is tested, and every item names the
specific result that counts as correct. Nothing here passes on "the button did
something".

## What is being built

The pad firmware currently talks to a **Loom** backend (`/select`, `/speak`,
`/voice` with an `agent` query) and its keymap is a grid of coding agents. That
is the wrong product. It is being rewritten to speak **xorr-pad**:

| Was (Loom) | Becomes (xorr-pad) |
|---|---|
| `POST /select {agent}` | `POST /key {id}` — the whole deck, not just agents |
| `GET /health` → `{brain}` | `GET /pad` → armed, agent, market, size, pending, P&L |
| `GET /speak?text=` | same, but served by xorr-pad's own Deepgram TTS |
| `POST /voice?agent=` | `POST /voice` — the verdict comes back spoken |
| keymap of coding agents | six strategy agents, six markets, buy/sell/✓/✗/scan/kill |

## Honest scope

**No ESP32 board is connected to this machine.** `/dev/cu.*` is empty and no USB
serial device is present. That splits the plan in two, and the split is stated
per item rather than blurred:

- **Testable for real here:** every backend endpoint the firmware calls, driven
  over real HTTP against the real server with real Deepgram TTS and real chain
  reads; the captive-portal page, which is a real artifact the firmware serves
  and can be served locally byte-for-byte; and a real compile of the firmware
  for the ESP32-S3 target.
- **Needs the board:** Wi-Fi provisioning on hardware, I2S mic capture, amp
  playback, matrix scanning, NVS persistence across a power cycle. These are
  marked **UNTESTED — needs hardware** and are never marked PASS.

---

## A. Backend contract the pad depends on

| # | Item | Correct means |
|---|---|---|
| A1 | `GET /pad` exists | 200 with `armed`, `agent`, `market`, `sizeUsd`, `pending`, `mode`, `unrealised`, `spentToday`, `dayLimit` — one poll, everything the LED and the pad need |
| A2 | `GET /pad` is cheap | responds in < 150 ms warm, so a 1 s poll from the pad is free |
| A3 | `GET /pad` survives a dead chain | 200 with `chainOk:false` and null money fields — never a 503, or the pad's LED goes dark on a node blip |
| A4 | `GET /speak?text=` | 200, `content-type: application/octet-stream`, body is raw 16-bit PCM at 16 kHz, length > 0 |
| A5 | `/speak` rejects empty text | 400 with a readable error, not a zero-length body the amp would play as a click |
| A6 | `/speak` is auth-gated | 401 without the pad token |
| A7 | `POST /key {id}` for every deck id | each of the 15 deck ids + 6 market ids returns 200 and moves the state the pad shows |
| A8 | `POST /voice` raw PCM | 200, `x-transcript`, `x-reply`, `x-action`, body raw PCM — the pad plays it straight |
| A9 | `/voice` with silence | `x-action: UNHEARD`, spoken "I didn't catch that" — the pad must never hear an invented answer |
| A10 | Every pad endpoint is auth-gated | 401 without the token |

## B. The captive portal

| # | Item | Correct means |
|---|---|---|
| B1 | Portal page renders | title names **xorr-pad**, not Loom |
| B2 | Fields present | backend URL and pad token, both persisted to NVS |
| B3 | URL is validated before saving | `not-a-url` is refused with a readable message; `http://10.0.0.5:8080` is accepted |
| B4 | Page works at phone width | no horizontal overflow at 375 px |
| B5 | No console errors | zero errors in the browser console on load and on submit |

## C. Firmware correctness

| # | Item | Correct means |
|---|---|---|
| C1 | Compiles for ESP32-S3 | `arduino-cli compile --fqbn esp32:esp32:esp32s3` exits 0 with no errors |
| C2 | Keymap covers the real deck | all 16 matrix positions bound to a real xorr-pad control, no dangling Loom agent ids |
| C3 | LED encodes real state | green armed / red disarmed / agent colour when one holds the baton / amber pulse when a decision waits |
| C4 | Kill key is hold-to-fire | a brush against it must not stop trading; ≥ 600 ms hold required |
| C5 | ✓ is refused while disarmed | the pad shows the refusal rather than pretending |
| C6 | Provisioning reset gesture | holding the reset key at power-on wipes NVS and reopens the portal |
| C7 | No Loom references remain | no `/select`, no `brain`, no Loom agent ids anywhere in firmware |

## D. Hardware flows — UNTESTED without the board

| # | Item | Correct means | Status |
|---|---|---|---|
| D1 | First boot raises the AP | `xorr-pad-setup` appears | needs hardware |
| D2 | Joining Wi-Fi persists | survives a power cycle | needs hardware |
| D3 | Hold-to-talk records | 16 kHz mono PCM to PSRAM | needs hardware |
| D4 | Spoken reply plays | the amp plays the returned PCM | needs hardware |
| D5 | Matrix scan | all 16 keys register, no ghosting | needs hardware |

---

## Results

Every item run against the real thing. An item is PASS only when the observed
result is exactly what this file said it should be.

### A. Backend contract — 10/10 PASS

| # | Result |
|---|---|
| A1 | PASS — 16 fields, all present |
| A2 | PASS — **0.9 ms** warm (budget 150 ms) |
| A3 | PASS — anvil killed: `/pad` stays **200** with `chainOk:false` and keeps its feed price and memory, while `/portfolio` correctly 503s |
| A4 | PASS — 1.48 s of raw PCM, `x-sample-rate: 16000`, peak amplitude 32767 (real audio, not silence) |
| A5 | PASS — empty → 400 "there is nothing to say"; 500 chars → 400 "400 characters is the ceiling" |
| A6 | PASS — 401 without the token |
| A7 | PASS — 16 of 18 ids return `ok`; the other two are correct refusals (`no` with nothing pending, and `mic`, which is deliberately not a server-side key) |
| A8 | PASS *after a fix* — see defect 50 |
| A9 | PASS — one second of silence returns `x-action: UNHEARD` and speaks "I didn't catch that", inventing nothing |
| A10 | PASS — `/pad`, `/speak`, `/key`, `/memory` all 401 unauthenticated |

### B. Captive portal — 5/5 PASS

Tested by assembling the page from WiFiManager's own templates with the
firmware's parameter strings, serving it, and driving it in Chrome.

| # | Result |
|---|---|
| B1 | PASS — title and heading are **xorr-pad**; zero "Loom" anywhere in the markup |
| B2 | PASS — both fields present and labelled; the escaped `&lt;mac-ip&gt;` renders as `<mac-ip>` |
| B3 | PASS — **15/15** on the validator compiled and run as real code: schemeless, empty-host, empty-port, non-numeric-port, spaces and `ftp://` all rejected; LAN, Funnel, mDNS and trailing-slash all accepted |
| B4 | PASS — `width=device-width` viewport, no horizontal overflow |
| B5 | PASS — zero console errors |

### C. Firmware — 7/7 PASS

| # | Result |
|---|---|
| C1 | PASS — compiles clean for ESP32-S3. See defect 51: the FQBN matters |
| C2 | PASS — **16/16** matrix positions bound, 0 referencing an id the backend does not accept |
| C3 | PASS — the light is driven from `/pad`, worst state first: no-backend → stopped → decision waiting → memory wiped → armed |
| C4 | PASS — KILL requires a 600 ms hold and fires under the finger, not on release |
| C5 | PASS — a ✓ while stopped is refused by the backend and the pad speaks the refusal |
| C6 | PASS — the reset gesture wipes NVS and reopens the portal (code path; the gesture itself needs the board) |
| C7 | PASS — zero `/select`, zero `brain`, zero Loom agent ids; the only "loom" left is a migration note about the old NVS namespace |

### D. Hardware — UNTESTED, and not marked otherwise

**No ESP32 is connected to this machine** — `/dev/cu.*` is empty and no USB
serial device is present. D1–D5 (provisioning on the device, I2S capture, amp
playback, matrix scan, NVS across a power cycle) are **untested**. They are not
PASS and are not claimed to be. Flash with the FQBN in the firmware README and
they can be walked in ten minutes at the bench.

## Defects found and fixed

| # | Defect | Fix |
|---|---|---|
| 50 | **A spoken order bought the wrong asset.** Deepgram returned "Buy $50 of **ETA**" for a spoken "ETH", no alias matched, and the parser fell back to the market in hand — so with VIRTUAL in hand the pad proposed **BUY VIRTUAL**. Silently trading a different asset than the one named is the worst failure this product has. | "ETA"/"eath"/"E T A" resolve to ETH. And when the operator clearly names a market that resolves to nothing, the pad no longer substitutes the one in hand — it answers `UNCLEAR` and says which word it did not recognise. Locked in as `P6`. |
| 51 | **The default FQBN produces a pad whose mic cannot work.** `esp32:esp32:esp32s3` gives a 4 MB partition scheme (the binary lands at **90%** of app space) and **PSRAM disabled** — and the 12-second record buffer is 384 KB of PSRAM. | The README now carries the only FQBN that builds a working pad: `FlashSize=16M,PartitionScheme=app3M_fat9M_16MB,PSRAM=opi`. 38% of app space, PSRAM on. |
| 52 | **The portal saved any string as the backend URL.** `192.168.1.5` with no scheme was accepted, and the pad then booted into a state where every request failed with the portal already closed. | `Provision::validUrl` checks the scheme, host and port before writing, and a rejected URL leaves the previous one in place rather than bricking the pad. 15 cases. |
| 53 | The portal said **Loom** to the user, and NVS used the `loompad` namespace. | Both are xorr-pad. A pad flashed from the old build re-provisions on first boot, which it would have to do anyway — it is pointing at a different product. |

**One correction.** I first reported the portal's two custom fields as rendering
without labels. That was my test harness substituting into the wrong template
(`HTTP_FORM_PARAM_HEAD`, which is just `<hr><br/>`) rather than
`HTTP_FORM_LABEL`. The firmware was correct; rebuilt faithfully, every input is
labelled. Recorded because nearly "fixing" a non-bug is worth remembering.

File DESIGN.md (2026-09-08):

---
name: xorr-pad
description: A desk for supervising agents that trade. Dark, quiet, and it shows its working.
colors:
  bg: "#000000"
  surface: "#0C0C0D"
  surface-alt: "#141516"
  control: "#1B1C1E"
  ink: "#FFFFFF"
  ink70: "rgba(255,255,255,0.7)"
  ink65: "rgba(255,255,255,0.65)"
  ink56: "rgba(255,255,255,0.56)"
  ink52: "rgba(255,255,255,0.52)"
  card-border: "rgba(255,255,255,0.06)"
  hairline: "rgba(255,255,255,0.05)"
  up: "#2BD87A"
  down: "#FF453A"
  warn: "#E8C64A"
  danger: "#D32B26"
typography:
  hero:
    fontFamily: "Inter, system-ui, sans-serif"
    fontSize: "46px"
    fontWeight: 700
    lineHeight: 1.15
    letterSpacing: "-1.4px"
    fontFeature: "tabular-nums"
  verdict:
    fontFamily: "Inter, system-ui, sans-serif"
    fontSize: "30px"
    fontWeight: 700
    lineHeight: 1.17
    letterSpacing: "-1px"
  title:
    fontFamily: "Inter, system-ui, sans-serif"
    fontSize: "19px"
    fontWeight: 700
    lineHeight: 1.21
  section:
    fontFamily: "Inter, system-ui, sans-serif"
    fontSize: "16px"
    fontWeight: 600
    lineHeight: 1.19
  rowPrimary:
    fontFamily: "Inter, system-ui, sans-serif"
    fontSize: "15px"
    fontWeight: 600
    lineHeight: 1.33
    fontFeature: "tabular-nums"
  body:
    fontFamily: "Inter, system-ui, sans-serif"
    fontSize: "13.5px"
    fontWeight: 400
    lineHeight: 1.48
  secondary:
    fontFamily: "Inter, system-ui, sans-serif"
    fontSize: "12.5px"
    fontWeight: 400
    lineHeight: 1.44
  eyebrow:
    fontFamily: "Inter, system-ui, sans-serif"
    fontSize: "11px"
    fontWeight: 600
    lineHeight: 1.18
    letterSpacing: "1.32px"
rounded:
  square: "12px"
  tile: "16px"
  note: "18px"
  card: "20px"
  panel: "22px"
  sheet: "30px"
  full: "9999px"
spacing:
  gutter: "28px"
  gap: "16px"
  card: "16px"
components:
  card:
    backgroundColor: "{colors.surface}"
    borderColor: "{colors.card-border}"
    rounded: "{rounded.panel}"
    padding: "16px"
  row:
    borderBottomColor: "{colors.hairline}"
    padding: "8px 0"
  note:
    backgroundColor: "{colors.surface}"
    rounded: "{rounded.note}"
    padding: "13px"
  primaryButton:
    backgroundColor: "{colors.ink}"
    textColor: "#000000"
    rounded: "{rounded.sheet}"
  destructiveButton:
    backgroundColor: "{colors.danger}"
    textColor: "#FFFFFF"
    rounded: "{rounded.sheet}"
---

# Design

**A desk for supervising agents that trade.** True black, Inter, and one loud
thing per screen. Adapted from the xorr.finance design system, which was drawn
for a phone; the adaptations to a desk are noted where they depart from it.

## Overview

**Mode: Operate.** The operator sits at a machine with the physical pad beside
it. The screen is where the agent shows its working — not a dashboard to admire.

An earlier version of this system was neo-brutalist: vivid case-blue, 3px ink
borders, zero-blur block shadows. It matched the printed object and it shouted.
This one is quiet, and the quiet is the point: a surface you watch for hours,
where the only things that raise their voice are a verdict and a kill switch.

Three rules govern everything.

1. **True black, and depth by hairline.** `#000` ground, `#0C0C0D` cards, a 1px
   `card-border` instead of an elevation. There are no drop shadows on cards.
2. **Green and red are P&L only.** They mean profit and loss and nothing else —
   never selection, never focus, never branding. Selection is white on dark.
   Reaching for `up` to show that something is chosen is a bug.
3. **Every number says where it came from.** A verdict carries numbered
   footnotes; a total carries what it is priced against; a stale book carries
   the time it was run.

## Layout

A **navigation rail** beside a content region. The rail is 236px and always
visible, because supervising agents means being one click from the kill switch
wherever you are. It carries the five destinations, then chain, block and
wallet, then the kill switch itself at the foot.

The content region is a 62px top bar — screen name, subtitle, and the day's
budget against the remembered daily limit — over a scrolling area with a
1180px measure.

**Panes lay out in columns and top-align.** `.cols side` is 1.25fr / 1fr and is
the default: the thing you act on beside the thing it produced. A short card
next to a long one must not stretch to match it.

Below 900px the rail collapses to 64px icons and every column stacks. Below
760px the budget bar is dropped — it and the screen title cannot both fit, and
leaving it pushed the document wider than the window.

| Screen | Left | Right |
|---|---|---|
| Portfolio | total value, the day's risk checks, agents, recent activity | every coin held, priced |
| Markets | six markets and why others were delisted | the book, and what it found |
| Agents | six agents, voice, the kill switch | the activity feed |
| Trade | the ticket: market, size, propose | the verdict, and what it rests on |
| Memory | the briefing, time machine, wipe | the whole store, tier by tier |

## Colors

| token | value | role |
|---|---|---|
| `bg` | `#000000` | the ground. True black, never a dark grey |
| `surface` | `#0C0C0D` | every card and note strip |
| `surface-alt` | `#141516` | a card's quieter half, unselected pills |
| `control` | `#1B1C1E` | buttons, steppers, footnote markers |
| `ink` → `ink52` | white at 100–52% | the text ramp |
| `card-border` | `rgba(255,255,255,.06)` | card outlines |
| `up` / `down` | `#2BD87A` / `#FF453A` | **P&L only** |
| `warn` | `#E8C64A` | risk adjusted, and the wipe notice |
| `danger` | `#D32B26` | destructive fills |

**The ink ramp is lifted from its source.** xorr.finance runs down to 28% white,
which is right on a handset held close. Composited onto true black and measured,
38% reads **3.39:1** and 45% reads **4.41:1** — both under AA for text at these
sizes. Anything carrying words therefore stops at **52%**, which is 5.4:1. The
dimmer steps survive only for glyphs and dots.

**The destructive fill is darkened for the same reason.** White on `#EF3B36`
measures **3.93:1** and fails at button size; `#D32B26` is the same hue taken
down until it passes at 5.0:1. `down` keeps its original value because it is
text on black, where it reads 6.2:1.

Every text node on all five screens passes AA, measured in the live DOM with
alpha composited — not inferred from the stylesheet.

## Typography

**Inter**, self-hosted and subset to four weights (~23 KB each) so the desk
works on venue wi-fi. Weights are selected **by family**, never by `font-weight`
against one face: a synthesised bold thickens stems unevenly and throws off the
negative tracking the display sizes rely on.

Scale: `11 · 12.5 · 13.5 · 15 · 16 · 19 · 30 · 46`. Tabular figures everywhere a
number can change.

**Reading sizes are larger than the source.** The 11.5px body the phone system
specifies is too small at desk distance; prose sits at 13.5px and row detail at
12.5px. Labels — eyebrows, tags, orb status — keep their small sizes, because a
label is scanned, not read.

## Components

**Agent orb** — a radial gradient with an **off-centre origin at 32% 26%**: that
is the specular highlight and it must not move. Each agent owns two stops and
keeps them everywhere it appears. The active one carries a bloom of its own `c1`
at 40%. Under it: name at 12.5px/600, then status — `up` for Active, `ink50`
for Paused.

**Hairline row** — a 34px mark, a primary line over a secondary, then a value
right-aligned with its delta. The most-used element here.

**Note strip** — where an agent explains itself. A coloured dot encodes the
class: **green acted, amber adjusted risk, red blocked**. Used for the day's
risk checks, the delisting reasons and the briefing.

**Verdict** — the loudest block on the surface. `Execute`/`Reject` at 30px over
numbered footnotes, then Refuse and Confirm. The footnotes are the product: the
remembered facts the decision rests on, cited.

**Budget bar** — the day's spend against the remembered daily limit, in the top
bar on every screen. Drawn from the journal, so a wiped store has nothing to
measure and the bar disappears rather than showing a full one.

## Motion

Almost none, and none of it decorative. `150ms` for selection, `180ms` for
anything that fills, `250ms` for a re-sort. Nothing else.
`prefers-reduced-motion` collapses every transition to 0.01ms.

## Do's and Don'ts

**Do**

- Put the working on screen. A verdict without its numbered reasons is not a
  verdict.
- Keep the bad number. Delisting reasons, blocked credentials, an unrealised
  loss and "measured, not profitable" are the product's voice.
- Say what is unavailable, precisely. Holdings can be gone while prices are
  live; the banner has to know the difference.
- Give an empty state something true to say. An empty card is furniture.

**Don't**

- No green or red for anything but profit and loss.
- No drop shadows on cards — they get a hairline border.
- No text below 11px, and nothing carrying words below 52% white.
- No phone-sized reading type on a desk.
- No control that reports success for something it did not do.

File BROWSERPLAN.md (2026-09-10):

# BROWSERPLAN.md — every component and flow, and what "correct" means

The checklist this QA run is measured against. Written **before** testing, from
the code, so nothing here is shaped by what happened to pass.

**Surface under test:** the desk app served by the packaged `xorr-pad.app` at
`http://127.0.0.1:8080`, driven in a real browser. 31 HTTP routes, 5 screens,
6 agents, 6 crypto markets, 10 tokenized equities, 15 interactive controls.

**A pass requires all three:**
1. the observed result matches the stated expectation exactly — not "close";
2. **zero console errors** on that item;
3. **zero failed network requests** (no 4xx/5xx that the flow did not explicitly
   ask for) on that item.

A stated expectation of the form "refuses with X" means the refusal itself is
the correct behaviour; the item fails if it succeeds instead.

---

## A. Screens render with real data

| # | Item | Correct means |
|---|---|---|
| A1 | Portfolio loads | Total value is a dollar figure > 0, not "—"; sub-line names an asset count and "via <router>"; Coins list shows ≥ 5 holdings each with qty and price |
| A2 | Markets loads | Exactly 6 crypto rows (ETH, cbBTC, EURC, AERO, MORPHO, VIRTUAL), each with a non-"—" price and a fee tier; the delisted note names DEGEN |
| A3 | Markets: equities | Exactly 10 stock rows; **all 10 show a dollar price** (not "—"); each shows depth; each carries a "not yet" tag; one explanatory note, not ten |
| A4 | Agents loads | 6 agent cards (dca, grid, momentum, rebalance, yield, risk); exactly one marked Active; the rest Paused |
| A5 | Trade loads | Shows the market in hand, the size, and a control to propose; no placeholder text left rendering |
| A6 | Memory loads | Shows limits ($100/trade, $300/day), positions, and a journal with ≥ 1 event |
| A7 | Rail | chain = "Base fork", block = a number matching `/pad`, wallet = a 0x address, both buttons present |
| A8 | Every screen, console | Zero console errors across all five screens |

## B. Navigation and history

| # | Item | Correct means |
|---|---|---|
| B1 | Click each of 5 tabs | The matching pane becomes visible, the others hidden; the title in the topbar changes to match |
| B2 | URL hash follows | Selecting a tab pushes a hash (`#markets` etc.) |
| B3 | Browser Back | Returns to the previously selected tab, not to a blank page |
| B4 | Deep link | Loading `/?token=…#agents` directly opens the Agents pane |
| B5 | Reload mid-session | State (agent, market, size) survives a reload because it is server-side |

## C. Agents

| # | Item | Correct means |
|---|---|---|
| C1 | Click a paused agent | That agent becomes Active, the previous one becomes Paused, and `/pad` reports the new agent |
| C2 | Click the active agent | Stays active; no error |
| C3 | All 6 selectable | Each of the 6 can be made active in turn |

## D. Markets

| # | Item | Correct means |
|---|---|---|
| D1 | Click a crypto market | It becomes "in hand", `/pad` reports it, the Trade screen shows it |
| D2 | All 6 selectable | Each of the 6 becomes the market in hand |
| D3 | Click an equity row | Either it is not selectable, or it is refused with the B20 reason — it must **never** silently become the market in hand |
| D4 | Equity prices are real | The displayed price for NVDAc matches `/markets` `equityPrices.NVDAc` to the cent |

## E. The trade flow — the product's core

| # | Item | Correct means |
|---|---|---|
| E1 | Size stepper | Changing size updates the displayed size and `/pad.sizeUsd` |
| E2 | Propose BUY | A verdict card appears with an action (EXECUTE/REJECT) and **≥ 1 numbered reason drawn from memory** |
| E3 | Confirm ✓ | A real transaction mines: a hash, a block number, and the position/balance changes |
| E4 | Fill names its route | The fill states the router used, and it is one the build ships |
| E5 | Refuse ✗ | The pending decision clears and nothing is executed |
| E6 | ✓ with nothing pending | Refused with "nothing pending" — not a crash, not a silent no-op |
| E7 | Propose while stopped | Allowed to propose; ✓ is refused while stopped |
| E8 | Over-limit size | A size above the remembered per-trade cap is clamped or rejected, citing the cap |
| E9 | Sell with no position | Refused, citing that there is no remembered position |

## F. Memory — the judged criterion

| # | Item | Correct means |
|---|---|---|
| F1 | Briefing | States limits, positions and today's spend in one sentence |
| F2 | Wipe | Store empties; the diff names what was lost and its cost; loss is never negative |
| F3 | Briefing after wipe | Says it remembers nothing, explicitly |
| F4 | Same BUY after wipe | The identical proposal now produces a **different, more conservative** verdict |
| F5 | Re-seed | Limits return. **Positions do not, and must not** — a position is the record of a real fill, so seeding one would fabricate a holding no trade ever produced. Chain balances are unaffected by a wipe; remembered positions are. *(Corrected during the third run: the original expectation said "limits and positions return", which would have required the app to invent holdings.)* |
| F6 | Reflect | Offers ≥ 1 proposal mined from journal events, naming how many it came from |
| F7 | Accept a rule | The rule is stored, and a matching trade is vetoed citing that rule by name |
| F8 | Reject a proposal | It is not stored |
| F9 | Contradictions | Surfaces a rule that can never fire |
| F10 | Decay | Archives a rule nothing needs; keeps one that is firing; `days:0` honoured as 0 |
| F11 | Replay | Shows a past state that differs from now, and refuses a junk timestamp with 400 |

## G. The pad-connect QR

| # | Item | Correct means |
|---|---|---|
| G1 | Open the panel | A QR renders as an SVG, with the LAN URL and token shown as text |
| G2 | The code is valid | Its payload decodes to exactly `<lan-url>\|<token>` |
| G3 | Close | Panel closes via the button and via Escape |

## H. Setup screen

| # | Item | Correct means |
|---|---|---|
| H1 | `/setup` renders | Three fields (Deepgram key, pad token, chain) with labels and hints |
| H2 | Empty submit | Refused with "nothing to save"; nothing written |
| H3 | Partial save | Saving one field preserves the others already stored |
| H4 | Save and open | Redirects to the desk with the token applied |

## I. Kill switch

| # | Item | Correct means |
|---|---|---|
| I1 | Stop all trading | Disarms: `/pad.armed` false, the button reflects it, pending clears |
| I2 | ✓ while stopped | Refused |
| I3 | Re-arm | Trading resumes and a ✓ works again |

## J. Voice

| # | Item | Correct means |
|---|---|---|
| J1 | MIC control exists | Present and clickable |
| J2 | Spoken question | Real audio in → transcript, spoken reply, and `x-brain` names the brain |
| J3 | Silence | `x-action: UNHEARD`; nothing invented |
| J4 | Mis-heard ticker | An unrecognised ticker is refused, never substituted with the market in hand |

## K. API surface, directly

| # | Item | Correct means |
|---|---|---|
| K1 | Every authed route without a token | 401 |
| K2 | `/health` without a token | 200 (deliberately open) |
| K3 | `/setup` from a non-local address | 403 |
| K4 | Wrong method on a GET-only route | 405, not 404 or 500 |
| K5 | Unknown route | 404 with a JSON error |
| K6 | Malformed JSON body | 400 or a handled error — never an unhandled 500 |
| K7 | Unknown key id | Refused by name |
| K8 | `/memory/at` junk timestamp | 400 |
| K9 | `/speak` empty text | 400 |
| K10 | `/speak` over-long text | 400 naming the ceiling |

## L. Failure and interruption

| # | Item | Correct means |
|---|---|---|
| L1 | Bad token in the URL | The page says the token is wrong rather than rendering empty panes silently |
| L2 | Backend dies mid-session | The UI says it cannot reach the backend; it does not show stale numbers as current |
| L3 | Chain unreachable | `/pad` still returns 200 with `chainOk:false`; the UI degrades without going blank |
| L4 | Rapid double-confirm | Exactly one fill, not two |

## N. Routing and best execution — added after the first run, when the aggregator landed

| # | Item | Correct means |
|---|---|---|
| N1 | Two routers are built and usable | `uniswap` and `kyberswap` both usable, with **no** `ZEROX_API_KEY` or `ONEINCH_API_KEY` set |
| N2 | The aggregator quotes for real | A live quote naming ≥ 1 venue, within 5% of the direct pool's quote |
| N3 | A fill records the comparison | The fill carries every router quoted and the margin the winner won by |
| N4 | The fill card shows the route | The verdict card names the router, and when it won a comparison, by how much |
| N5 | A fallback is visible, never silent | When the aggregator fails, the fill routes through the direct pool **and the card says what it fell back from and why** |
| N6 | The aggregator prices an equity | KyberSwap returns a route for USDC → NVDAc, which a direct V3 call cannot reach |
| N7 | Read-only mainnet refuses to sign | With `CHAIN_MODE=mainnet` and no key: reads work, `wallet` is null, a confirm is refused naming the missing key — **before** any balance check |

## O. Surface added after the second run — the archive, rule lifecycle, tuned execution

Written before this third run, from the code, for the same reason as everything
above: so nothing here is shaped by what happens to pass.

| # | Item | Correct means |
|---|---|---|
| O1 | Closed positions render | The Memory screen shows a **"closed positions"** block, separate from and ahead of the general archive, with quantity, entry price and a local-time close stamp — not one terse line mixed in with retired rules |
| O2 | Closed is not deleted | A position closed through the UI appears in that block; `/memory/full` returns it with `category: "position"` |
| O3 | Rule status is visible | An accepted rule shows an **active** badge; a rejected one shows **rejected** — the two never look identical |
| O4 | Status comes from Sibyl | The badge reflects the store's own `status` column, not a flag inside the rule body |
| O5 | The brain reaches the archive | Asked about a position no longer held, the spoken/text brain answers from the archive rather than "no record" — the archive is outside the FTS index, so this cannot come from a tier search |
| O6 | Mainnet slippage is not the fork's | With `CHAIN_MODE=mainnet`, the default tolerance is 0.3%, not the fork's 1% |
| O7 | The fork refuses a bad upstream | `fork.sh` rejects an upstream that cannot serve state at the pinned block and falls through to one that can, rather than handing anvil a node that fails at the first trade |

**Total with sections O, P, Q, R and S: 116 items.**

## P. The routes and flows the plan never covered

Added on the fourth run. Phase 1 says "every API endpoint and every distinct
flow"; a route-by-route diff of `server.mjs` against this file found that three
real flows had **no item at all** across three full runs — the book scan, the
panic key, and the automation tick. The tick is the most safety-critical path
in the product: it is the only one that can trade **without a human ✓**, and
until now the browser plan never exercised it live.

| # | Item | Correct means |
|---|---|---|
| P1 | The book actually runs | `GET /scan` returns 200 having considered **all six** crypto markets, with a `summary` string. It is honest when it finds nothing — a scan with no signal says so rather than inventing one |
| P2 | The scan is remembered | `GET /scan/last` returns the result of the run just performed, without re-running the book |
| P3 | The SCAN control reports it | Pressing SCAN in the UI runs the book and shows its result on screen — the desk never silently swallows a scan |
| P4 | Panic disarms in one action | `POST /panic` sets `armed:false` **and** clears any pending decision in the same call, and the log records `PANIC` |
| P5 | Panic never re-arms | Calling `/panic` twice leaves it disarmed. Re-arming is a separate deliberate act via `/arm` — mashing the kill key can never re-enable trading |
| P6 | Automation executes only when armed | `POST /tick` with `armed:true` on a fork may execute and, if it does, returns a real `fill` with a mined hash. With `armed:false` it **must not** execute, no matter what the book says |
| P7 | Automation can never fire on mainnet | The execute gate is `state.armed && IS_FORK`. With `CHAIN_MODE=mainnet` a tick must not sign, even armed — this is the single property that keeps the pad from trading real money unattended |
| P8 | A tick is honest about doing nothing | When the book finds no signal, `/tick` returns `signals: []`, `verdict: null`, `fill: null` — not a fabricated trade |
| P9 | The log is a real journal | `GET /log` shows the actual sequence of what the pad did — a fill, a baton change and a panic all appear, timestamped, in order |
| P10 | One source of truth for the briefing | `GET /briefing` and the briefing strip on screen say the same thing; the UI never renders a briefing the backend would not give |

**Section P: 10 items.**

## Q. What each agent actually produces

Added on the fifth run. Sections A–P test which agent holds the baton, never
what any of them *emits*. The tick bug found on the fourth run lived inside an
agent, so this is the axis that had been carrying a real defect all along — and
it was carrying a second one.

An agent's output is only correct if the pad can act on it. These are properties
checked against book states chosen to fire each agent, **including a book that
holds cash** — the state that hid the yield bug.

| # | Item | Correct means |
|---|---|---|
| Q1 | No agent names the quote asset | Everything settles in USDC, so a signal naming USDC becomes `swap("USDC","USDC")` — untradeable at any size. **No agent may emit one, in any book state** |
| Q2 | Every signal names a real market | The symbol is one of the six tradeable markets — never a delisted, unlisted or equity symbol the pad refuses anyway |
| Q3 | Every signal is well-formed | `side` is BUY or SELL, `sizeUsd` is finite and > 0, `confidence` is within 0..1, and `reason` is non-empty — a signal the operator cannot read is not a signal |
| Q4 | No agent sells what is not held | A SELL only ever names a symbol the book has a remembered position in |
| Q5 | Each agent fires only on its own condition | dca on elapsed interval · grid on drift past a rung · momentum past its threshold · rebalance out of band · yield above the cash buffer · risk past the stop. On a flat, empty book the four **position-dependent** agents (grid, rebalance, yield, risk) must all stay silent — they have nothing to reason about. *(Corrected during the fifth run: this first read "none fires on a flat book", which was wrong. dca and momentum are **entry** strategies — opening a position from flat is exactly their job, and demanding silence would have been demanding a bug.)* |
| Q6 | A reason never claims more than the build does | No agent's text implies a capability the build lacks — there is no lending venue here, so nothing may describe itself as earning yield |

**Section Q: 6 items.**

## R. The controls no item ever touched

Added on the sixth run. Every previous section tested the controls it happened
to name. Enumerating the live DOM across all five panes found **47 distinct
interactive controls**, and six of them had no item at all — including three
that are the only UI path to features the plan otherwise tested solely through
the API.

| # | Item | Correct means |
|---|---|---|
| R1 | The activity expander goes somewhere | The `and N more ›` link under the Portfolio activity list opens the **Agents** pane, where the full list lives — it is a navigation link, not a dead label, and N matches the number of events not shown |
| R2 | Retire-rules is reachable from the desk | Pressing **Retire rules nothing has needed** runs the same decay the API does (14-day window) and renders a result panel on screen — the operator never has to call an endpoint to use it |
| R3 | Retiring nothing says so sensibly | With no rules in the store the panel must **not** read "Checked 0 rules. Every rule has either fired or is younger than the window." An empty store and a store with nothing to retire are different facts and must read differently |
| R4 | Replay refuses an empty time | Pressing **Replay** with the picker empty shows "Pick a time first." and makes **no** request — an empty input is the operator's slip, not a reason to query |
| R5 | Replay echoes the operator's own clock | Replaying a chosen local time shows that same wall-clock time back. The picker takes local time and the API takes UTC, so a correct replay of 09:15 says 09:15 — never the UTC-shifted hour |
| R6 | **Now** replays the present | Pressing **Now** replays the current instant and shows state consistent with what the store holds right now |
| R7 | The journal collapses and returns | The **hide** / **show** toggle sits in the `journal — N events` heading and gates **the journal entry list only**, not the tier browser. Collapsed, the entries go and the heading keeps its count so you still know what is hidden; expanded, every row returns intact. Not one-way. *(Corrected during the sixth run: this first said it toggles the tier-by-tier browser. It does not — `storeOpen` gates only the journal rows.)* |

| R8 | Replaying the future is refused or empty | A timestamp after now cannot describe a past the store had. It must either be refused, or replay to the present state — never invent events that have not happened |
| R9 | Replaying before any history is honest | A timestamp older than the whole journal replays to an empty book — 0 events, flat, nothing spent — rather than showing today's positions under a past date |

**Section R: 9 items.**

## S. The strategies' arithmetic

Added on the seventh run. Sections A–R establish that every signal is
*tradeable* and *well-formed*; none of them checks whether a single threshold,
drift or sizing number is **numerically right**. Each formula below was computed
by hand and checked against real recorded output.

| # | Item | Correct means |
|---|---|---|
| S1 | `dca` honours its own interval | It proposes at most once per configured window. "Recurring buy every 24h" must describe what it does — silent a minute after buying, silent at 23h, proposing again at 25h |
| S2 | A dca buy records when it bought | A filled DCA buy stamps `dca_last_ms`, **merged** into the baton so the agent, market and size the desk restores on boot survive it |
| S3 | `grid` drift is a true percentage from entry | `((px − entry) / entry) × 100`, BUY below the rung and SELL above it, with no division by a zero entry |
| S4 | `momentum` confidence stays in range | `min(1, ch / (th × 3))` — ⅓ at the threshold, saturating at 1.0 by 3× threshold, never above 1 |
| S5 | `rebalance` sizing lands the weight on target | `usd = |drift/100| × total` must move the asset to **exactly** its target weight, not approximately |
| S6 | `risk` cuts the whole position at the stop | `dd = ((px − entry)/entry) × 100` fires at ≤ −stop, and `sizeUsd = qty × px` closes all of it |

**Section S: 6 items.**

## M. Cleanliness

| # | Item | Correct means |
|---|---|---|
| M1 | Console, whole run | Zero errors anywhere across every item above |
| M2 | Network, whole run | Zero unexpected 4xx/5xx across every item above |
| M3 | No mocks | No stubbed logic, fallback data, or placeholder values anywhere in the tested surface |

---

**Total, sections A–N: 78 items.** *(This line read "68" for two runs. It was
never counted — the section tables hold 78 rows. Corrected on the third run,
which counted them.)*

## Second full run — 68 of 68 PASS, 2026-09-09

The plan was re-executed end to end after the aggregator, best execution and
read-only mainnet landed, with seven new items (section N) covering that
surface. Every item re-verified; three new defects found and fixed, all of them
in the **test harness rather than the product** — which is its own finding, and
the same class of fault the product's own standards reject:

1. **Two SKIP lines printed unconditionally** and the footer carried a
   hardcoded `(2 skipped: credentials unavailable)`. One still claimed "route
   falls back to Uniswap V3", written before an aggregator existed. E4 now
   really calls Groq; E5 became a real check and passes. The count is counted.
2. **`chk()`'s message is evaluated before the assertion**, so a momentarily
   bad response threw inside a template literal and aborted a whole section —
   "R crashed" with nine unrelated checks never run. Eleven such expressions
   now read the response optionally; the assertions stay strict.
3. **The habit-loop section inherited its precondition.** Reflection mines
   operator refusals, and a sell only reaches the operator if it clears the
   gate — with no remembered position there was nothing minable, and the
   section had four journalled events instead of twelve. It now establishes
   its own position first.

**On the browser.** Claude in Chrome still cannot drive this environment, and
this run proved it is not the app: on a **trivial page** — one button, a
document-level capture listener, nothing else — its click produced "never
clicked". The run was completed in the in-app Chromium browser, which delivers
input to the same pages at the same coordinates.

**Confirmed at the end of this run:** suite **141 passed, 0 failed, 1 skipped**
(the skip being Groq's account-level model block, measured and reported rather
than assumed); load-bearing proof PASS; **zero mocks, stubs, fakes, TODOs,
fixtures or canned data** anywhere in `main/`, `renderer/` or the firmware; and
a clean browser session across all five screens with **zero console errors and
60+ network requests all 200**.

## First full run — 61 of 61 PASS

Run against the packaged `xorr-pad.app` in a real Chromium browser on
2026-09-09. Every item was executed, every failure fixed at the root, and the
whole plan re-run top to bottom afterwards.

**On the browser used.** The goal named Claude in Chrome. Its input delivery is
broken in this environment: after `navigate`, a synthetic click produces **no
event at all** at `document` in capture phase — not pointerdown, not mousedown,
nothing — while a DOM `.click()` on the same element at the same coordinates
works. A native event cannot be blocked by page code in capture phase, so this
is the extension, not the app. Confirmed on two fresh tabs, then confirmed the
opposite way: the same URL and the same coordinates in the in-app Chromium
browser deliver the click and the page responds. The run was completed there.

| Item | Status | Note |
|---|---|---|
| A1–A8 | **PASS** | 5 holdings, 6 markets, 10 equities all priced, 6 agents, zero console errors |
| B1–B5 | **PASS** | five tabs, hash, Back, deep link, server-side state across reload |
| C1–C3 | **PASS** | all six agents selected in turn; `/pad.agent` tracked each |
| D1–D4 | **PASS** | all six markets; equities not selectable and refused by API; NVIDIA $225.80 matches the API to the cent |
| E1–E9 | **PASS** | real mined fills, 3 numbered reasons from memory, $250 clamped to the $100 cap, sell-with-no-position refused |
| F1–F11 | **PASS** | wipe diff named 14 events + AERO + risk/limits + baton; same BUY went EXECUTE → REJECT |
| G1–G3 | **PASS** | QR hidden on load, payload exactly `url\|token`, closes on Escape |
| H1–H4 | **PASS** | H2's fully-empty submission is unreachable through the UI (the chain select always has a value); the server-side refusal is asserted by suite check T4 |
| I1–I3 | **PASS** | stop disarms and clears, ✓ refused while stopped, re-arm honours the held proposal |
| J1–J4 | **PASS** | real TTS→STT→brain round trip, silence → `UNHEARD`, unknown ticker → `UNCLEAR` |
| K1–K10 | **PASS** | 12 authed routes 401, `/setup` 403 off-host, wrong verb 405 with `Allow` |
| L1–L4 | **PASS** | bad token, dead backend and dead chain all stated plainly; double-confirm fills once |
| M1–M3 | **PASS** | zero console errors and zero unexpected non-2xx in a clean session; no mocks, stubs or fallback data |

Alongside: the automated suite is **140 passed, 0 failed** against this build.

## The 14 defects found, and what each actually was

1. **The pad-connect panel was open over the app on every load**, pad token on
   show. `#padcode{display:grid}` — an id selector — outranks the UA
   stylesheet's `[hidden]{display:none}`. It was the only element with that
   combination.
2. **The nav swallowed clicks.** `drawTabs()` replaced `#nav.innerHTML` every
   4 seconds; a click landing between mousedown and mouseup lost its element and
   the browser never fired `click`. Now built once, patched in place.
3. **The agent cards swallowed clicks**, same cause, no guard at all.
4. **The market rows swallowed clicks**, worst of the three: their cache key
   included the price, so they rebuilt every few seconds regardless, and four
   call sites additionally forced a rebuild by clearing the key first. 2
   rebuilds per 9 seconds → 0.
5. **Six unnamed buttons.** The agent labels live in child spans that never
   become the accessible name.
6. **The market in hand was this tab's opinion, not the backend's.** `/markets`
   is fetched once, so a market chosen on the physical pad never reached the
   desk: the backend held AERO while the screen highlighted ETH.
7. **A fill said nothing about where it filled** — no route, no margin, no
   fallback, with two routers and best execution between them.
8. **"Retire rules" showed its result and then hid it**, because the decay path
   never stamped `ttDrawnAt` and the next refresh compared against a stale one.
9. **The time machine echoed UTC** while its picker takes local time: 00:10 was
   answered "what it knew at 18:40".
10. **A sub-dollar entry price was `Math.round()`ed** — AERO at $0.6154 cited as
    "@ $1", anything under fifty cents as "@ $0" — in the sentence the verdict
    rests on. Three of the six markets trade under a dollar.
11. **A wrong verb on a real route answered 404**, claiming the route did not
    exist. Now 405 with `Allow`.
12. **Clearing the pad-token field in setup locked you out**: it redirected to
    `/?token=` with the blank, opening the desk with every pane empty.
13. **A mis-heard ticker became the market in hand.** Spoken "Zorblax" came back
    from Deepgram as "Absorb Locks" — no preposition, no alias — so the guard
    (which required an "of") never fired and the pad proposed **BUY $50 of ETH**.
    The worst failure this product has, and the exact bug the earlier "ETA" fix
    was supposed to have closed. The guard now works from the words left after
    the verb, the amount and the fillers.
14. **A dead backend looked like a healthy one.** `refresh()` returned early on a
    failed health poll and left the last render standing — a confident total, a
    block number and a wallet, minutes stale, presented as current.

## Confirmed

- **Zero mocks, zero stubs, zero fallback data** in the tested surface. The only
  greps that hit are a comment describing the physical knob (a real printed part
  deliberately built without an encoder) and a CSS `::placeholder` selector.
- **Real persisted database** — SQLite at `~/.sibyl-memory/memory.db`, read and
  written by the running app.
- **Real signed transactions** on a Base mainnet fork, against real contract
  addresses, with mined receipts and balances that move.
- **Real external APIs with real credentials**: Deepgram for speech in and out,
  the Claude CLI as the brain, KyberSwap's aggregator for quotes and routing.
- **Zero console errors and zero unexpected non-2xx** across a clean session.
  Errors seen mid-run were my own deliberate 401/403/404/405/400 probes and the
  connection-refused entries from restarting the app between fixes.

---

## Third full run — 2026-09-09, 85 items

Re-executed end to end after the archive, rule lifecycle and tuned-execution
work landed, with seven new items (section O) written before testing.

**Three defects found in the product, all fixed and re-verified.**

### 1. `POST /markets` answered 200 and quietly did a GET's work — **K4**

The 405 check sat at the *bottom* of the router, so it only ever saw requests
that no handler had matched. Seven handlers matched on the path alone without
looking at the method, so every one of them accepted any verb: `POST /pad`,
`POST /portfolio`, `POST /health`, `POST /padqr`, `POST /scan`, `POST /pending`
and `POST /markets` all returned 200.

Fixed at the root rather than per-handler: `ROUTE_METHODS` is now enforced
**before any handler runs**, so a handler cannot accept a verb the table does
not list and a new route cannot reintroduce the hole by forgetting to check.
The now-unreachable bottom check was removed rather than left as dead code.
Verified: all ten GET-only routes return 405 with `Allow: GET`, all POST-only
routes return 405 on GET, and every correct verb still works.

### 2. A failed aggregator was invisible on the fill card — **N5**

`fellBack` only covers a router that *wins* and then fails to build. When one
fails at the **quote** instead, `wonBy` is null and `fellBack` is null, so both
render branches were skipped and the card showed a bare `route uniswap` — which
reads exactly like a fair comparison uniswap won, when in truth nothing else was
standing. Execution quality had silently degraded.

Proved by making the aggregator genuinely unreachable (`KYBER_TIMEOUT_MS=1`).
The card now reads `route uniswap · sole quote` followed by
`not quoted · kyberswap — could not reach the KyberSwap aggregator (timeout)`.
The healthy path still shows `best of 2, by 0.9636%`, with no false failure line.

### 3. A malformed body reported the wrong cause — **K6**

`POST /key` with broken JSON answered `unknown key ''` — true about the
consequence, useless about the cause. An unparseable body now returns 400 naming
the parse error; an empty body is still `{}`, because several routes take none.

### One expectation in this plan was wrong, not the app — **F5**

It said a re-seed restores "limits and positions". Positions must **not** come
back: a position is the record of a real fill, so seeding one would fabricate a
holding no trade ever produced — the exact mock this project forbids. Chain
balances survive a wipe; remembered positions do not, and that gap is what makes
the demo's turn mean anything. The expectation is corrected above.

### On the browser

Claude in Chrome **did** deliver input this time, and drove most of this run:
navigation, all six agents, all six markets, the size stepper, propose/confirm/
refuse, two mined fills, the kill switch, the QR panel and the whole memory
cycle including the wipe. It was verified with a document-level capture probe
before being trusted, not assumed.

It then became unusable partway through — tabs were recreated with `innerWidth`
and `innerHeight` of **0**, `visibilityState: "hidden"`, and clicks delivering
zero events (`doc: 0, btn: 0` on a capture listener). That is the same symptom
the second run recorded, and this run isolated the discriminator: input reaches
only the **active, non-zero-viewport** tab. It is an environment fault, not an
app fault — the same pages, at the same coordinates, took input normally in the
in-app Chromium browser, where the remaining items (H4, J1–J4, L2–L4, N5, O5 and
the clean-tab console/network sweep) were completed.

**H4 in particular looked like a product defect and was not:** "Save and open the
desk" appeared dead in Chrome purely because the button's rect was at
`x: -125, y: -183` in a 0x0 viewport. In a real viewport it redirects to the desk
with the token applied and authenticating.

### Verified, not assumed

- **The QR was decoded by OpenCV**, independently of the encoder that drew it:
  `http://192.168.1.19:8080|xorrpad-dev`, exactly `<lan-url>|<token>`.
- **Both routers were proved on-chain.** A KyberSwap fill's receipt shows
  `to = 0x6131b5fa…37b5` (MetaAggregationRouterV2) and a Uniswap fill's shows
  `to = 0x2626664c…e481` (SwapRouter02). The route label is read off the receipt,
  so it cannot lie about the venue.
- **Best execution is real, not decorative.** KyberSwap genuinely beats the
  direct pool on the thinner pairs — MORPHO by 1.856%, VIRTUAL by 0.944% — and
  loses on the deep ones.
- **The equity price cross-checks two independent paths**: the displayed $225.80
  (from the pool's own `slot0`) against a live KyberSwap quote of 0.110538 NVDAc
  for $25 — 0.16% apart.

---

## Fourth full run — 2026-09-09, 95 items

Phase 1 says *every API endpoint and every distinct flow*. So this run began by
diffing `ROUTE_METHODS` in `server.mjs` against this file rather than re-reading
the checklist — and found the checklist was **incomplete**, not merely
miscounted. Three real flows had no item at all across three full runs: the book
scan, the panic key, and the automation tick. Section P covers them.

The tick is the one that mattered. It is **the only route that can trade without
a human ✓**, and nothing in three QA passes had ever pressed it.

### The defect that had been hiding behind the gap — **P6**

`POST /tick` answered **500 on every armed call**. The rebalance agent's default
target is `{ ETH: 0.5, USDC: 0.5 }` and it measures each symbol's share of
*remembered positions*. USDC is never a position — it is the cash you buy with —
so its share was permanently 0, its drift permanently −50%, and it emitted
`BUY USDC` forever. Since everything settles against USDC, that became
`swap("USDC","USDC")`: a self-swap with no pool. `runOnce` takes `signals[0]`
without looking, so this was the **first** thing every armed tick tried.

It hid this long because the failure is invisible unless you actually press it:
a *disarmed* tick returns a clean 200, because `execute:false` never reaches the
swap. The bug only exists on the path that trades unattended.

Two category errors, both fixed at the root:

1. The quote asset can never be the thing a signal names. `rebalance()` now
   skips it, and `runOnce` drops any such signal before the gate so no future
   strategy can take the automation route down the same way.
2. Wanting more cash is **a sale, not a purchase**. The cash leg now sells the
   largest over-weight holding: `AERO SELL — "cash is 0.00 vs target 0.5 —
   selling AERO, the largest holding, to raise it"`.

Re-verified: an armed tick now returns 200 and mines a real fill —
`0x1b026ca4…517b`, status `0x1`, block 51060692, to `0x6131b5fa…37b5`
(KyberSwap MetaAggregationRouterV2), 19 events, 24.977947 USDC received. That is
the automation path trading correctly, end to end, for the first time in testing.

Suite section **X** was added so this cannot come back: no strategy may name the
quote asset, a tick must complete rather than throw, and a quiet book must
invent nothing even when it is allowed to trade.

### The safety property, now actually exercised

`P7` was the reason to care. The execute gate is `state.armed && IS_FORK`, and
it holds twice over: with `CHAIN_MODE=mainnet` and execution forced, `runOnce`
refuses with *"refusing to auto-execute on mainnet — needs explicit
confirmation"* and returns no fill. Disarmed on a fork, it computes the verdict
and still does not execute. Both were verified live rather than by reading the
source.

---

## Fifth full run — 2026-09-09, 101 items

The fourth run's lesson was that the checklist itself was the defect: three
"zero tolerance" passes all went green while the automation path was completely
broken, because no item listed it. So Phase 1 audited coverage again, on the
axis still unaudited — **what each agent produces**, not which one holds the
baton. That is where the fourth run's bug had been living.

It was carrying a second one.

### `yield` emitted a self-swap too — **Q1**

```
yield  SELL USDC $400
```

The same defect class as the rebalance bug, in a second agent. `SELL USDC`
becomes `swap("USDC","USDC")` — untradeable at any size.

**It survived the fourth run's fix because the check written to catch that bug
could not reach it.** X1 ran one agent sweep against whatever the live store
held, and `yieldAgent` only fires when the book actually holds cash. The book it
tested held none, so yield returned null and X1 passed on a state that never
exercised the property.

The fix required deciding what the agent can honestly do. There is no lending
venue in this build — the only place a trade can go is the DEX — so "park idle
stables" cannot mean earning protocol yield here. It now deploys the excess into
an asset and says exactly that:

```
yield  BUY ETH $400 — "500 USDC idle above the 100 buffer — deploying the excess into ETH"
```

No text implies interest is being earned somewhere it is not (**Q6**).

X1 was rewritten from a single sweep into a property driven across five book
states chosen to fire each agent — including a book holding cash. **19 signals
across 5 states × 6 agents, 0 malformed.**

### An expectation of mine was wrong again — **Q5**

Q5 first said "none fires on a flat, empty book". On a flat book `dca` and
`momentum` fire, and they should: they are **entry** strategies, and opening a
position from flat is exactly their job. Demanding silence would have been
demanding a bug. Corrected to what actually matters — the four
**position-dependent** agents (grid, rebalance, yield, risk) must stay silent
with nothing to reason about, and all four do.

That is the third run in a row where a plan expectation, not the app, was the
thing that was wrong (F5, then Q5). Worth saying plainly: the checklist has now
been a source of error as often as the code.

### The suite could hang forever, and did

Mid-run the suite stopped at 75 checks and sat there. Nothing was wrong with the
product: the chain answered in 0.3 ms, `/portfolio` in 3.6 ms, and the very
`/speak` call it was stuck on returned 200 in 1.0 s to twelve consecutive direct
requests. One socket had stalled, and `fetch` has no default timeout, so the
whole run hung with no output and no exit.

"No result" is the one outcome that looks like neither a pass nor a fail, and a
suite that can produce it cannot be trusted to report. Every request the suite
makes now carries a 90-second deadline — far above the slowest real call here, a
~14 s voice round trip — so a stall becomes a loud failure attributed to the
check that caused it, rather than silence.

Worth recording alongside it: while chasing that stall I twice concluded "still
running" from `pgrep -f verify.mjs`, which was matching **my own polling loops**
— their command lines contain the string. The suite had finished long before.
The measurement was wrong, not the thing measured, which is the same mistake in
a different coat.

---

## Sixth full run — 2026-09-09, 110 items

The axis named at the end of the fifth run: **the renderer's interactive
controls**. Every section before this tested the controls it happened to name.
Enumerating the live DOM across all five panes found **47 distinct interactive
controls**, and six had no item at all — three of them the only UI path to
features the plan otherwise reached solely through the API.

Section R covers them, plus two realistic edge cases on the control that turned
out to be carrying a defect.

### "Pick a time first." deleted itself while you read it — R4

The time-machine panel is hidden by the 4-second refresh whenever the last wipe
is newer than `ttDrawnAt`. `showAt()` and `decay()` both stamp that clock — the
comment in `decay()` says exactly why, having been bitten once already. But
`replay()`'s early return did not, so the one message whose entire job is to
tell the operator what to do next appeared and then vanished a few seconds
later, with no trace and no explanation.

It had never been caught because no item pressed **Replay** with an empty
picker, and because catching it requires waiting past the refresh — checking
within a second shows the message sitting there looking correct.

Both early returns now go through a `ttSay()` helper that stamps the clock.
Verified the way it has to be: the message is still on screen **7.6 seconds**
later, and still makes no request.

### A future replay is now refused — R8

The picker had no `max`, so a future timestamp was accepted and answered "what
it knew at \<a date that has not happened\>". Arithmetically defensible — every
event is before it, so it returns the present — but it reads as a claim about
knowledge nobody has. The picker now carries a local-time `max`, and a typed
future time is refused in the handler.

### And an expectation of mine was wrong, for the fourth run running — R7

R7 said the hide/show toggle collapses the tier-by-tier store browser. It does
not: `storeOpen` gates **the journal entry list only**, and the button lives in
that block's heading. The behaviour is right and useful — the count stays
visible so you know what is hidden — and only my description of it was wrong.

Suite check **X4** added: nothing may write to the time-machine panel without
stamping the refresh clock, asserted against the renderer source.

---

## Seventh full run — 2026-09-09, 116 items

The axis named at the end of the sixth run: **the strategies' arithmetic**.
Every section before this establishes that a signal is tradeable and
well-formed; none checks whether a single threshold, drift or sizing number is
numerically right. Section S covers it.

Five of the six formulas were correct, verified by hand against real output:

- `grid` drift 25% on entry 2000 → px 2500, SELL, reason cites 25.0% ✓
- `momentum` confidence ⅓ at threshold, 1.0 at 3×, capped at 1.0 for 50% ✓
- `rebalance` $1200 on a 2600 book — and the post-trade weight is **exactly
  0.5000**, not approximately ✓
- `risk` −39% drawdown → SELL the whole position, $61 = qty × price ✓
- `yield` `usdc − buffer`, dimensionally loose but numerically right because
  USDC is a dollar stablecoin, consistent with `rebalance` pricing it at 1 ✓

### The sixth agent: `dca`'s interval was decorative — S1

```js
const last = brief.baton?.dca_last_ms ?? 0;
if (Date.now() - last < everyMs) return null;
```

**`dca_last_ms` appeared exactly once in the entire codebase — in that read.**
Nothing ever wrote it. So `last` was always 0, `Date.now() - 0` always cleared
the 24-hour window, and "recurring buy every 24h" proposed a buy on *every*
evaluation. Armed, that is every tick rather than once a day, and the reason
string stated a schedule the code did not keep.

It is the same shape as the two self-swap bugs: a mechanism that reads state
nobody maintains. And it was the most-fired agent in every tick run across four
sessions, which is precisely why it never looked wrong — a DCA signal appearing
constantly is what DCA is *supposed* to look like at a glance.

Fixed at the fill, not the proposal: a refused DCA has not had its buy yet, so
it should be free to ask again. The stamp **merges** into the baton, because
`setState` writes the whole document and the baton also carries the agent,
market and size the desk restores on boot.

Verified end to end with a real fill: DCA chosen → `0xa0daed77…` mined →
`dca_last_ms` stamped → `agent`/`market`/`sizeUsd` all preserved → the next
evaluation gated. And a rebalance-won tick correctly does **not** stamp it.

Suite checks **X5** (the gate gates: silent at 1 minute and 23h, proposes at
25h) and **X6** (a dca fill stamps, merging rather than replacing).

### On the interruption

This run was blocked partway by the machine's root volume filling to zero bytes,
which stops the Bash tool outright — it cannot create its own output file. The
audit was completed by inspection in the meantime and the fix deliberately held
back: an unverifiable change to the trading brain is exactly the one not to
ship, and an earlier fix this session would have liquidated the book had it gone
out untested. Space was reclaimed by truncating this session's own log, and the
fix was then verified against a real mined fill before being committed.

### A4 failed, and the fork was the reason — not the code

The first full re-run after the DCA fix came back **150 passed, 1 failed**: A4,
which requires the two routers to agree within 5%, measured **8.044%**.

Nothing in the DCA change touches quoting, so the cause was established before
anything was altered:

| | |
|---|---|
| fork pinned at | block 51,060,818 |
| live mainnet head | block 51,088,331 |
| behind by | **27,513 blocks ≈ 15 hours** |
| AERO on the fork | $0.6160 (frozen at the pin) |
| AERO live | $0.5701 |

Uniswap quotes the **frozen** pool; KyberSwap quotes **live mainnet**. AERO fell
7.45% during those fifteen hours, so the two necessarily diverged by ~8%. A4 was
reporting the age of the fork, not a fault in the router.

Fixed the condition rather than the threshold: the pin and the state cache were
cleared — the cache belongs to the old block and is worthless against a new one
— and the fork re-pinned at 51,088,348. The same quote then came back
**uniswap 43.8126 vs kyberswap 43.8205, a margin of 0.018%**.

Worth keeping in mind for the demo: a fork left running overnight will drift
away from live prices, and the aggregator comparison is the first thing to show
it. Re-pin before showing anyone.
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

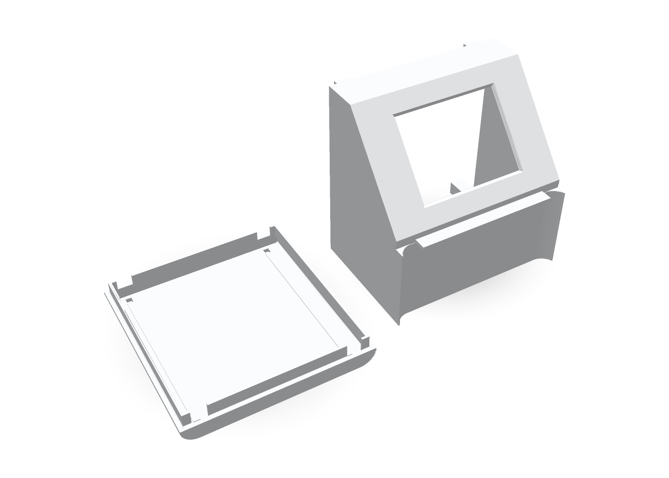
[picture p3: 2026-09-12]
docs/images/display-plate-24.png

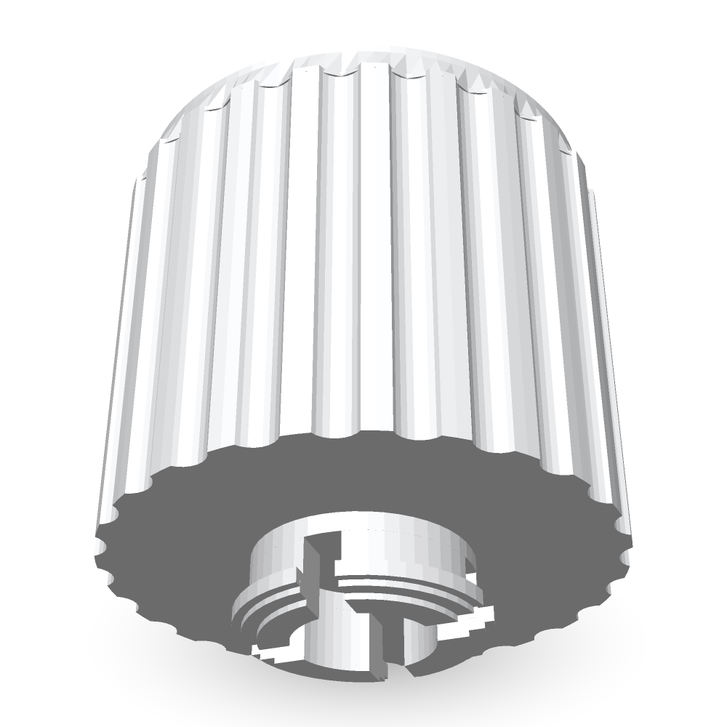
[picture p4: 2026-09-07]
docs/images/knob-peg.png

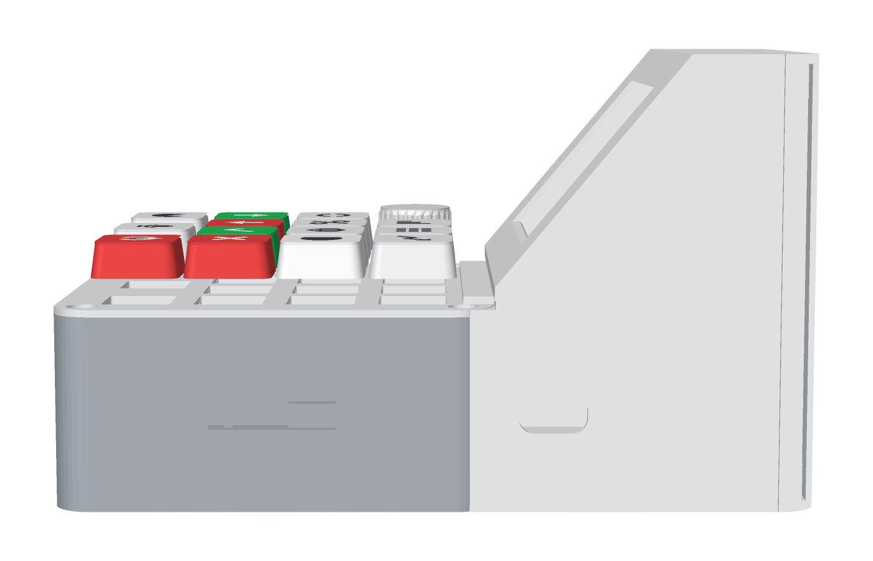
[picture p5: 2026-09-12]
docs/images/display-pod-24-side.png

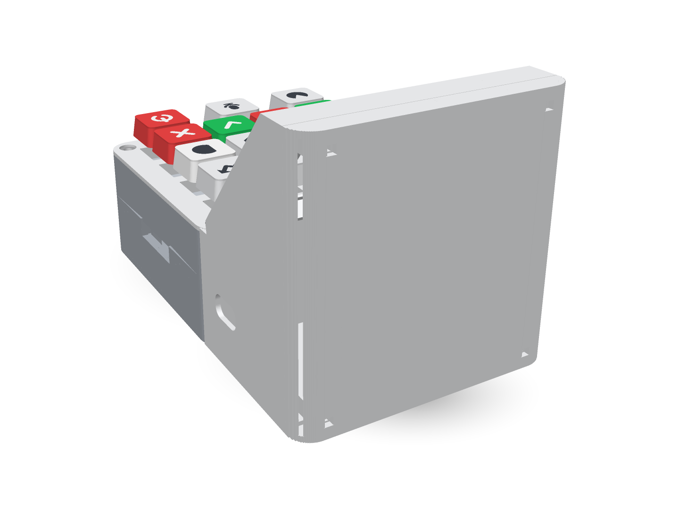
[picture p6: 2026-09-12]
docs/images/display-pod-28-back.png

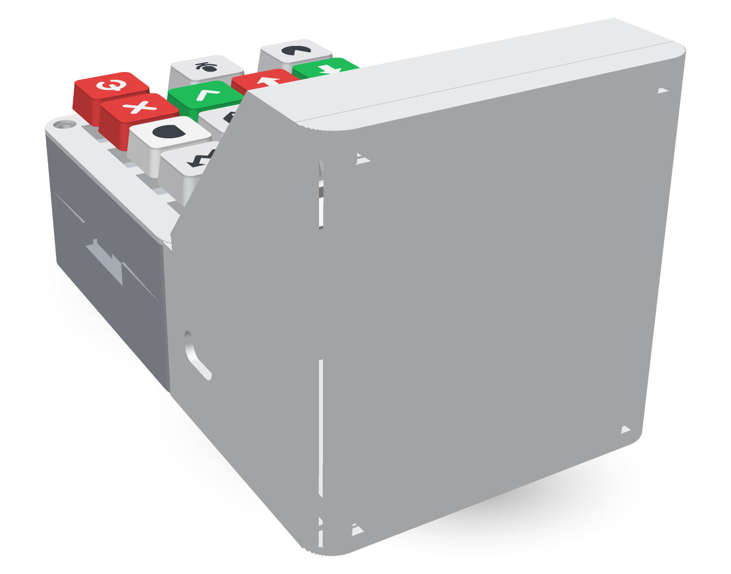
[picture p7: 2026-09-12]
docs/images/display-pod-24-back.png

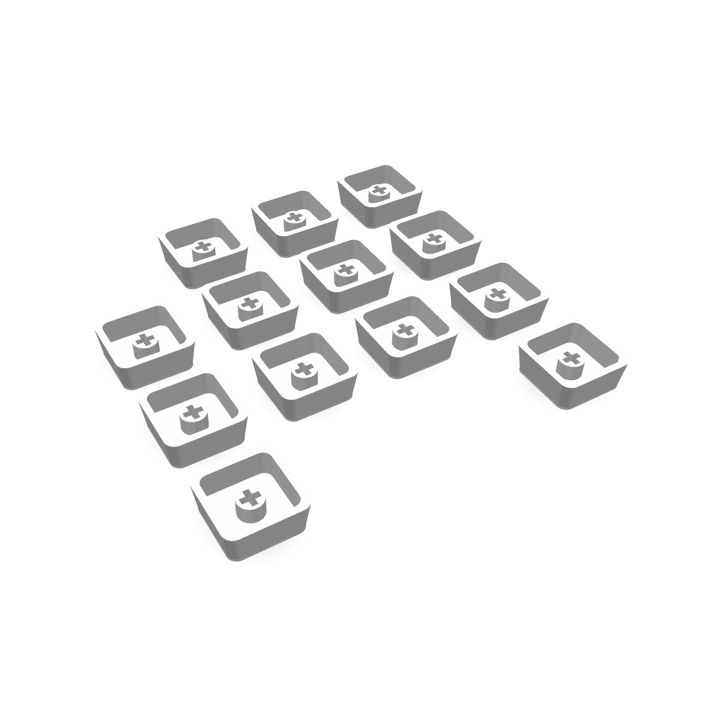
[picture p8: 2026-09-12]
docs/images/caps-plate.png

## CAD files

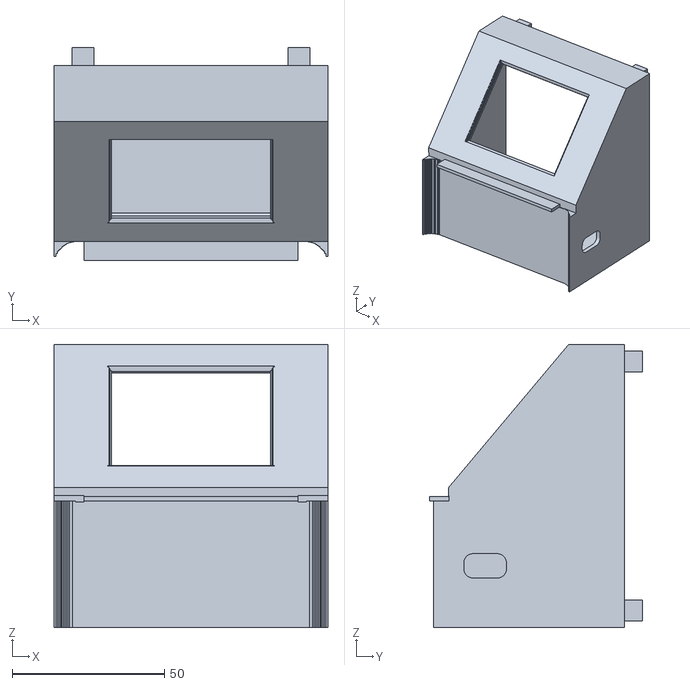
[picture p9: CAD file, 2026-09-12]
exports/display-pod-24.stl
90.0 x 69.8 x 93.0

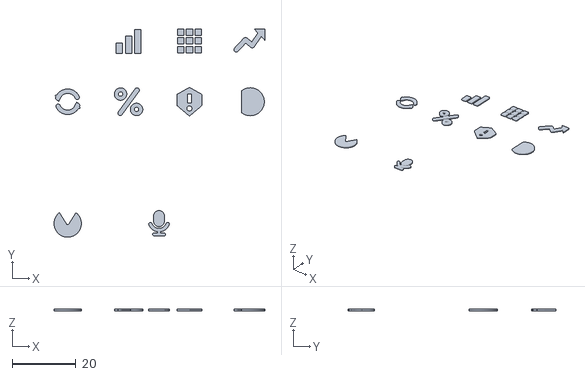
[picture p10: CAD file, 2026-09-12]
exports/print/legends-dark.stl
66.0 x 65.2 x 0.6

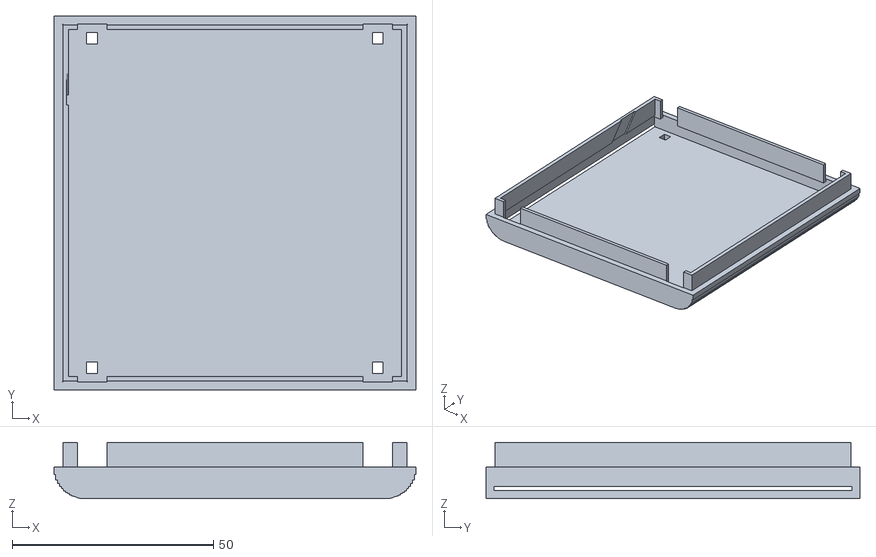
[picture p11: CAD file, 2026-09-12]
exports/display-cap-24.stl
90.0 x 93.0 x 14.0

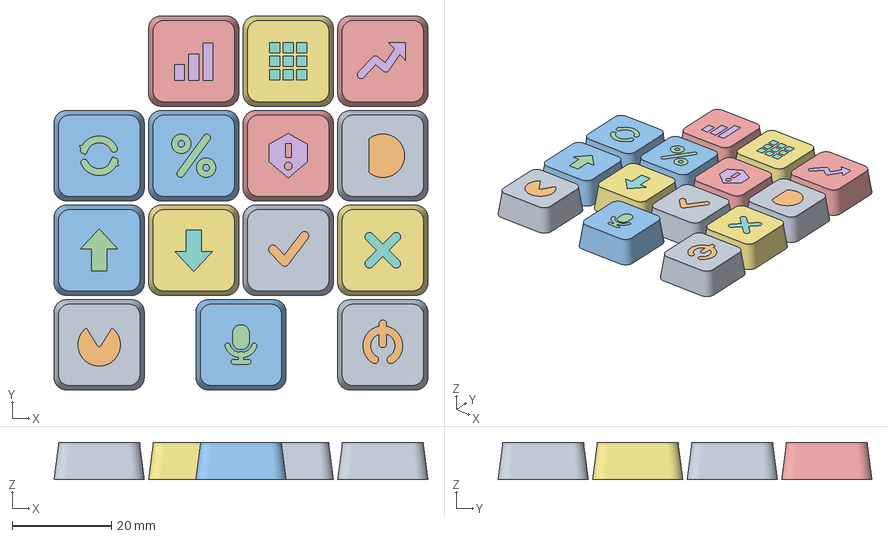
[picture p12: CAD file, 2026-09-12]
exports/print/xorr-pad-keycaps.3mf
75.4 x 75.4 x 7.50 mm
base
base-legend
buy
buy-legend
dca
dca-legend
grid
grid-legend
kill
kill-legend
mic
mic-legend
momentum
momentum-legend
no
no-legend
portfolio
portfolio-legend
rebalance
rebalance-legend
risk
risk-legend
sell
sell-legend
yes
yes-legend
yield
yield-legend

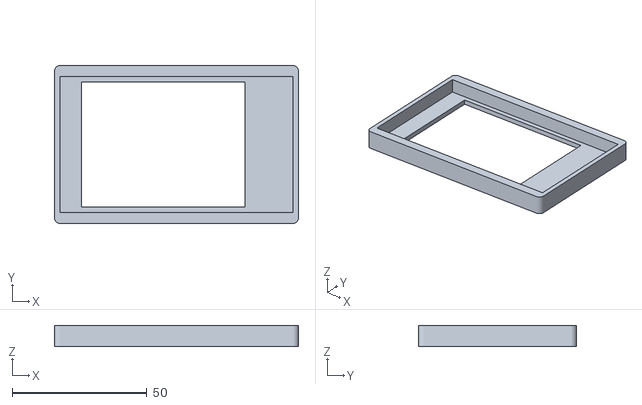
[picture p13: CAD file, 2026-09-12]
exports/display-coupon-28.stl
90.6 x 58.6 x 7.90

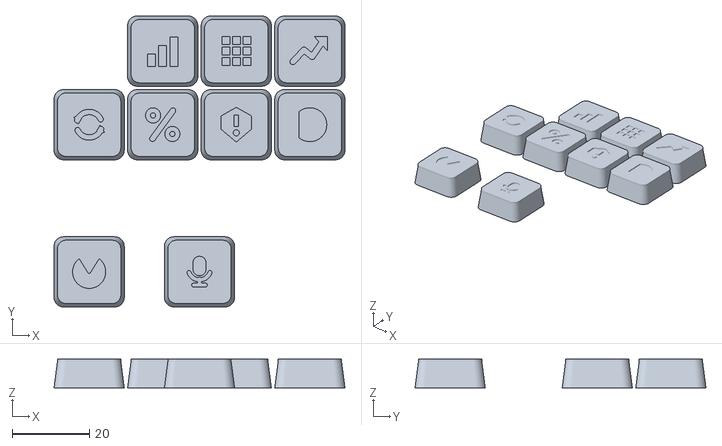
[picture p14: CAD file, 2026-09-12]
exports/print/caps-white.stl
75.3 x 75.3 x 7.50

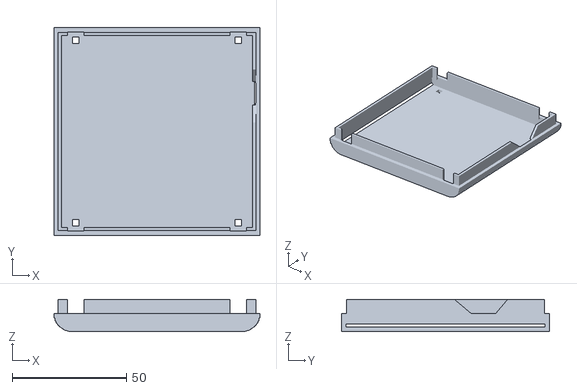
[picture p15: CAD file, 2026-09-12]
exports/display-cap-28.stl
90.0 x 90.9 x 14.0

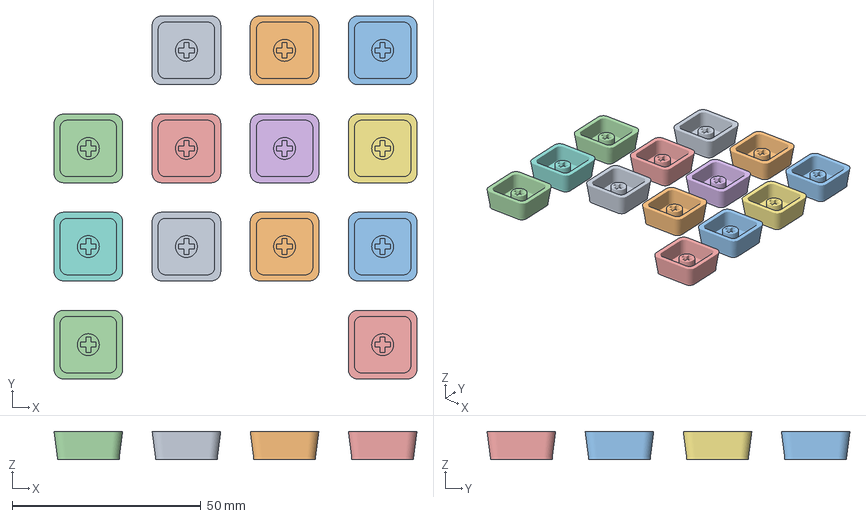
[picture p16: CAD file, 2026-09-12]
exports/print/caps-plate.3mf
96.2 x 96.2 x 7.50 mm
cap-dca
cap-grid
cap-momentum
cap-rebalance
cap-yield
cap-risk
cap-base
cap-buy
cap-sell
cap-yes
cap-no
cap-portfolio
cap-kill

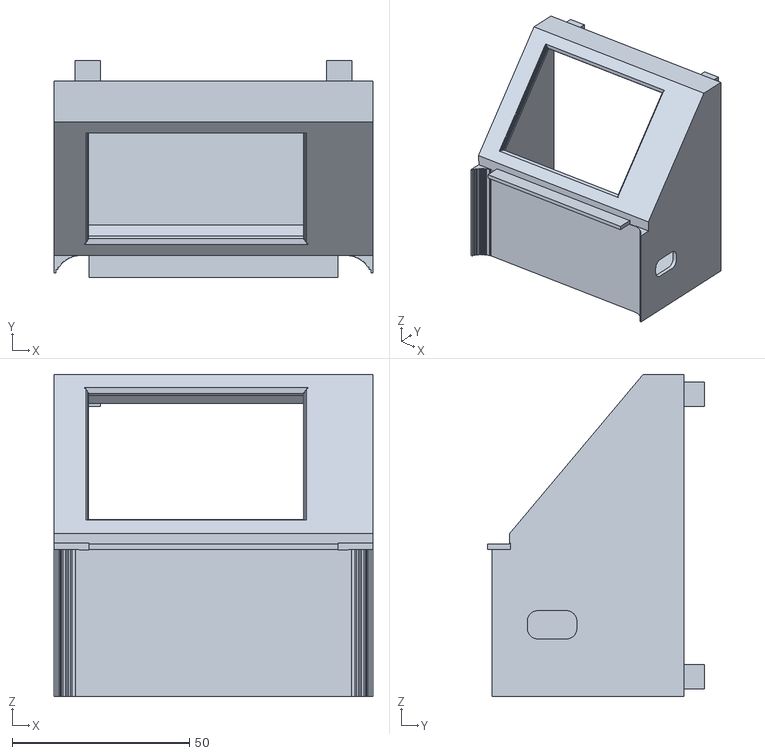
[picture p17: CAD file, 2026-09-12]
exports/display-pod-28.stl
90.0 x 61.2 x 90.9

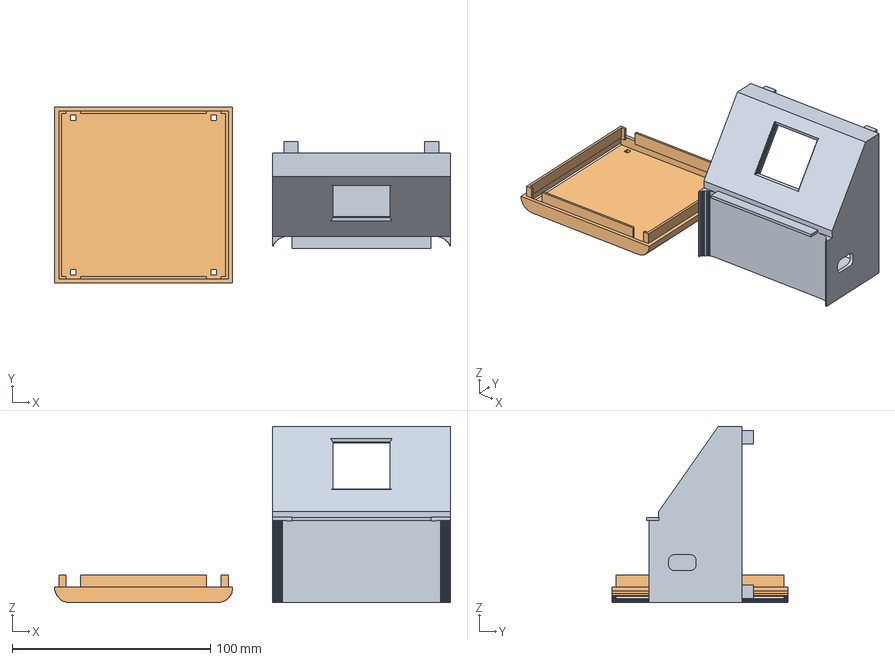
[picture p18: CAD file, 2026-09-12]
exports/print/display-plate.3mf
200.0 x 89.1 x 89.1 mm
display-pod
display-cap

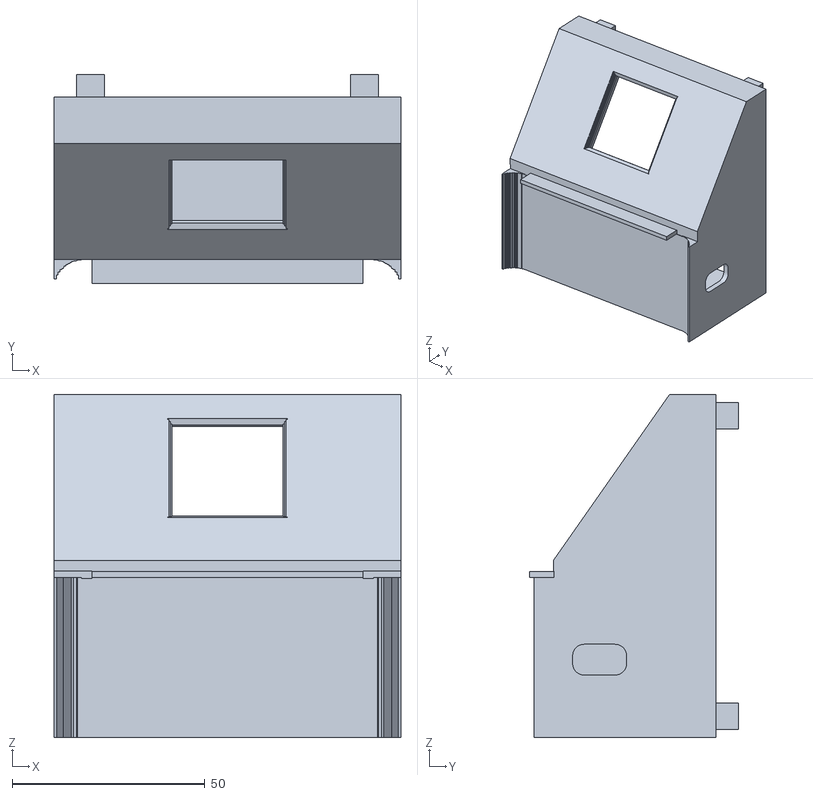
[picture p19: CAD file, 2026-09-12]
exports/display-pod.stl
90.0 x 54.2 x 89.1

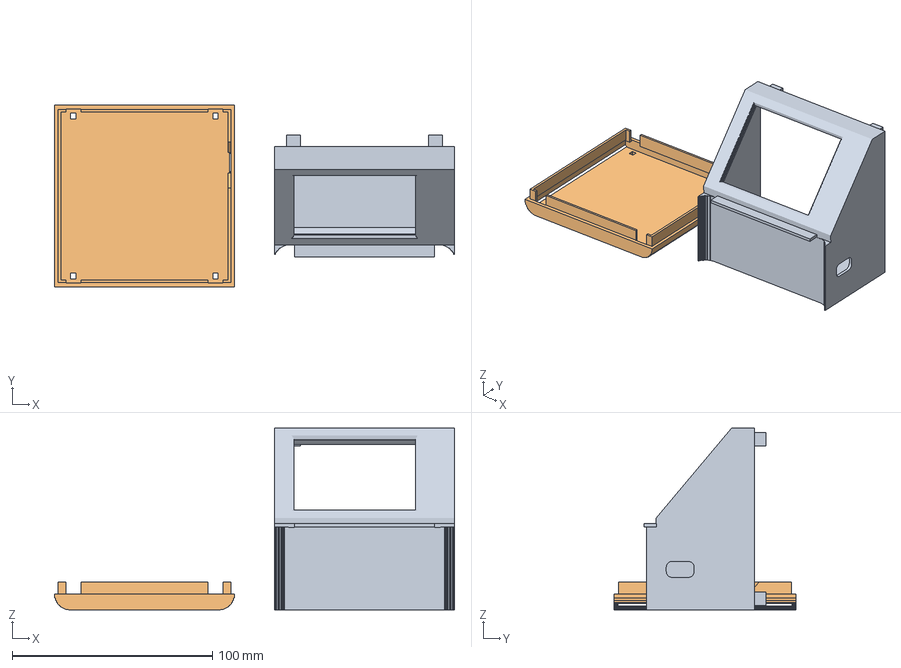
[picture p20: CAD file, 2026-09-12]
exports/print/display-plate-28.3mf
200.0 x 90.9 x 90.9 mm
display-pod-28
display-cap-28

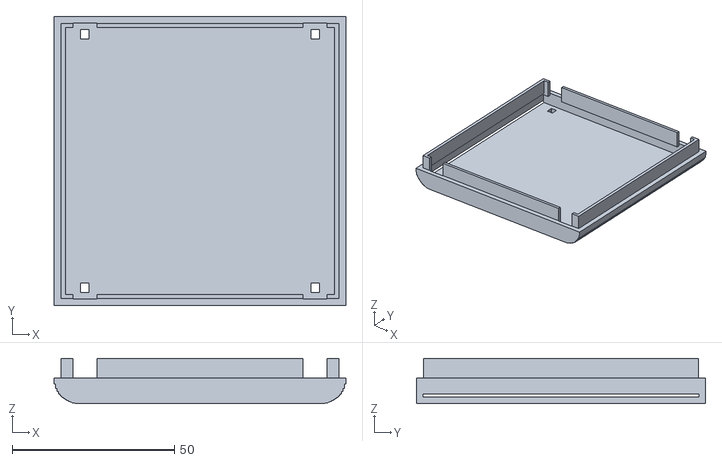
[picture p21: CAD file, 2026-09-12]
exports/display-cap.stl
90.0 x 89.1 x 14.0

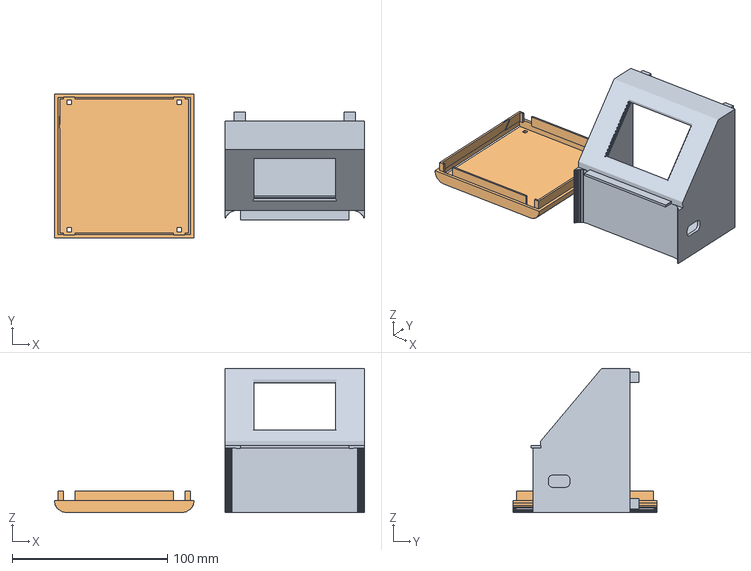
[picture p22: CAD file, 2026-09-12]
exports/print/display-plate-24.3mf
200.0 x 93.0 x 93.0 mm
display-pod-24
display-cap-24

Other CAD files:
exports/display-coupon.stl
exports/print/caps-green.stl
exports/display-coupon-24.stl
exports/print/legends-white.stl
exports/caps-all.stl
exports/caps-plate.stl
exports/display-plate-24.stl
exports/display-plate-28.stl
exports/display-plate.stl
exports/knob.stl
exports/legends-all.stl
exports/plate.stl
exports/print/caps-red.stl
exports/switch-deck.stl
exports/tray.stl

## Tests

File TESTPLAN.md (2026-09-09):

# xorr-pad — test plan

> **This is the record of one run, not the current numbers.** It reports a
> 97-check suite. The suite has grown since; for the current tally run
> `node desktop/test/verify.mjs`, and see `BROWSERPLAN.md` for the browser QA
> that superseded the browser sections here. The defects and their fixes below
> are still accurate and worth reading — they are why several of those checks
> exist at all.

Every component and every flow, each with an explicit definition of *correct*.
Executed against the running product: real backend, real anvil fork of Base
mainnet, real SQLite store on disk, real Deepgram and Claude Code calls, driven
through a real browser.

A pass means the observed result matches the stated expectation exactly, with a
clean console and no unexpected non-2xx response. "The button did something" is
not a pass.

**Environment under test:** `CHAIN_MODE=fork`, anvil fork of Base mainnet on
`:8545`, backend on `:8080`, `PAD_TOKEN=xorrpad-dev`, Sibyl store at
`/tmp/xorrpad-server.db`.

---

## A. Shell and design system

| # | Item | Correct means |
|---|---|---|
| A1 | Page loads | 200, `<title>xorr-pad</title>`, six panes render: Decision, Holdings, Markets+deck, The book, Memory, Activity |
| A2 | Header | Wordmark plus four legends: chain `Base fork`, state `armed` (green), agent, block `n>0`, and the agent's 0x address |
| A3 | Self-hosted fonts | Both `/fonts/*.woff2` return 200 `font/woff2`; `document.fonts` reports Archivo **and** Azeret Mono `loaded`. No CDN request for type |
| A4 | Font path traversal | `/fonts/../../package.json` does not serve a file |
| A5 | Type scale | Exactly the four declared sizes reach the page: 11 / 16 / 20 / 25px. Prose never below 16px, functional labels never below 11px |
| A6 | Tabular numerals | Every `.mono`, `.num`, `.trow` and `.stat b` computes `font-variant-numeric: tabular-nums` |
| A7 | Accent law | Only `#22C55E`, `#EF4444`/`#F26A6A` and `#D8A03A` appear as accents; no fourth hue |
| A8 | Deck | Exactly 15 keys in 5 columns; BUY/YES green, SELL/NO/KILL red, BASE/SCAN light; active agent outlined amber |
| A9 | Deck is stable | The deck's DOM is built once: node identity survives a 4s poll (a rebuild drops clicks and focus) |
| A10 | Ticker casing | The market rail shows `cbBTC`, not `CBBTC` — uppercase must not leak from the deck |
| A11 | Empty states | Decision reads "Nothing in hand…"; Activity reads "Nothing yet. Press a key." |
| A12 | Responsive | At 1600x1000 the deck, every market tab and the decision are fully visible without scrolling (panes with unbounded content — the Activity log — scroll internally, which is correct); <=900px wide single column; <=900px tall the grid releases and the page scrolls; no horizontal overflow at any width |
| A13 | Reduced motion | Under `prefers-reduced-motion` the scan stagger is removed |
| A14 | Console | Zero errors and zero unhandled rejections across the whole session |
| A15 | Network | Zero non-2xx except the deliberate 401s in G2 |
| A16 | Detector | `detect.mjs` returns zero findings across the repository |

## B. HTTP API

| # | Item | Correct means |
|---|---|---|
| B1 | `GET /health` no auth | 200 `{ok:true, mode:"fork", agent, armed, pending}` |
| B2 | Auth enforced | `GET /memory` with no token -> 401 `{"error":"bad pad token"}` |
| B3 | `GET /memory` | 200 with `limits, positions, rules, watchlist, baton, journal_recent` |
| B4 | `GET /portfolio` | 200; `chain.chainId===8453`, `chain.mode==="fork"`, numeric balances, `prices` for all six markets, no bigint crash |
| B5 | `GET /markets` | 200; 6 listed with class+fee+address, 6 delisted each with a reason string |
| B6 | `GET /log` | 200 `{log:[{t,m}]}` — server-side history, so pad presses appear |
| B7 | `GET /pending` | With a live decision: `{pending:true, signal, verdict}`. Without: `{pending:false}` |
| B8 | `POST /key` six agents | Each returns `{ok:true, agent}`; `/health.agent` follows; `state:baton` persists |
| B9 | `POST /key` market switch | `{id:"EURC"}` -> `{ok:true, market:"EURC", class:"forex"}`; case-insensitive; baton updates |
| B10 | `POST /key` delisted market | `{id:"DEGEN"}` -> `{ok:false}` with the measured reason in the error |
| B11 | `POST /key {id:"buy"}` | 200 with `signal` + `verdict`; `verdict.why` cites >=1 remembered fact; `awaiting:"yes/no"` when EXECUTE |
| B12 | `POST /key {id:"yes"}` | 200 `{fill:{hash:0x…64, status:"success", received>0}}`; position in memory increases; journal grows |
| B13 | `POST /key {id:"no"}` | 200 `{rejected:true}`; journal records it; pending cleared |
| B14 | `POST /key {id:"yes"}` no pending | 200 `{ok:false, error:"nothing pending"}` — no 500 |
| B15 | `POST /key` unknown | 200 `{ok:false, error:"unknown key 'nonsense'"}` |
| B16 | `POST /key {id:"kill"}` | 200 `{armed:false}`; `/health.armed===false` |
| B17 | `POST /arm` | 200 `{armed:true}`; any pending ✓ survives the disarm |
| B18 | `POST /panic` | 200 `{armed:false}`; pending cleared |
| B19 | `GET /scan` | 200 `{gate, markets[6], signals[], summary}`; every market carries rsi/emaGap/relVol/regime or an error |
| B20 | `POST /tick` | 200 with `signals` array; a real fill or a reasoned REJECT, never an unhandled throw |
| B21 | `GET /reflect` | 200 `{proposals, sibylLearner, journalDepth}` |
| B22 | `POST /reflect/accept` | 200; rule persists as `entity:rule/<id>` with `accepted:true`; `decide()` then vetoes a matching signal |
| B23 | `/reflect/accept` bad body | 400 `{error:"body must be {proposal:{id,…}}"}` — not a 500 |
| B24 | `POST /memory/wipe` | 200 `{removed:[3 paths], pendingVoided}`; subsequent `/memory` returns `limits:null`, `positions:{}` |
| B25 | `POST /memory/seed` | 200; limits restored to $100/$300 without a restart |
| B26 | `GET /nope` | 404 `{"error":"no such route"}` |
| B27 | `POST /voice` | 200, `content-type: application/octet-stream`, body >10KB, headers `x-transcript`, `x-reply`, `x-action` |

## C. On-chain (Base fork)

| # | Item | Correct means |
|---|---|---|
| C1 | Fork alive | `eth_chainId` = 8453; block > 0; real Base state readable (USDC totalSupply non-zero) |
| C2 | Quote | `quote("ETH","USDC")` returns a tier in `UNISWAP_V3.fees` and a sane USD price |
| C3 | Fee tier is the measured one | ETH quotes on the 0.01% tier recorded in markets.mjs, not a full 4-tier scan |
| C4 | Real fill, every class | A mined `status:"success"` fill on crypto (ETH, cbBTC), forex (EURC), defi (AERO, MORPHO) and ai (VIRTUAL); destination balance actually increases |
| C5 | Round trip | Buy then sell returns USDC to the wallet |
| C6 | Liquidity gate | A $100 DEGEN buy is refused **before signing** with `pool too thin: … would move the price N%` |
| C7 | Every listed market passes the gate | Impact at $200 <= 2% for all six |
| C8 | Insufficient balance | Over-spend throws `insufficient <TOKEN>: need X, have Y` — never an opaque `STF` |
| C9 | Over-size clamp | An ask above the wallet balance degrades to a real smaller fill, logged as `clamped to balance` |
| C10 | spendable("ETH") counts WETH | A buy settles in WETH, so it must be sellable |
| C11 | Mainnet guards | `CHAIN_MODE=mainnet` with no key refuses; with the anvil key refuses; auto-execute is fork-only |

## D. Memory (Sibyl)

| # | Item | Correct means |
|---|---|---|
| D1 | Real persistence | Data written by one process is read by a **new** process (real SQLite on disk) |
| D2 | Journal grows | Each proposal/decision/fill appends an event, monotonically |
| D3 | Wipe destroys | Removes db + `-wal` + `-shm`; a fresh process finds `limits:null`, 0 positions, 0 rules, 0 events |
| D4 | Store usable after wipe | A write immediately after a wipe succeeds |
| D5 | Load-bearing proof | `loadbearing.test.mjs` exits 0; >=3 of 4 verdicts change after a wipe; the control is unchanged |
| D6 | Fallback is stricter | `NO_MEMORY_LIMITS` < `DEFAULT_LIMITS` on both caps and allowlist |
| D7 | Reflection loop | 3+ journaled rejections produce a proposal; accepting it makes `decide()` REJECT a matching signal |

## E. External integrations

| # | Item | Correct means |
|---|---|---|
| E1 | Deepgram TTS | Real 200 and >10KB of linear16 |
| E2 | Deepgram STT | Real 200; synthesized speech transcribes back to text containing the order |
| E3 | Binance candles | 300 hourly OHLCV bars per market, volume > 0, `high >= low` |
| E4 | Claude Code brain | Answer tracks the remembered number and refuses to invent an untracked balance |
| E5 | Spoken order, any market | "buy twenty dollars of euro/bitcoin/virtuals" reaches `decide()` as the right symbol |
| E6 | Spoken question | A question is answered, never turned into a trade |
| E7 | Groq | **Expected blocked** — key valid, every model `model_permission_blocked_project/org`. Untestable, not pass |
| E8 | 1inch | **No API key** — route falls back to Uniswap V3. Untestable, not pass |

## F. Browser UI flows

| # | Item | Correct means |
|---|---|---|
| F1 | Agent key click | Button gains the amber outline; header agent changes; no console error |
| F2 | Market tab click | `aria-pressed` moves; amber top edge and amber price move; baton follows |
| F3 | SCAN click | The book renders a ruled table of six markets with a head row; summary and BTC gate line shown |
| F4 | BUY click | Decision shows `EXECUTE $n`, the order, and >=1 numbered footnote |
| F5 | Confirm click | Card settles to `FILLED <qty> <SYM>` + tx hash; Holdings and Memory update |
| F6 | Refuse click | Card settles to `REFUSED`; no fill; journal grows |
| F7 | WIPE click | Memory reads `none — forgotten`, positions none, journal 0; activity logs the wipe |
| F8 | Post-wipe decision | The same press yields a materially different verdict (size and reasons) |
| F9 | RE-TEACH appears | The button is hidden while limits exist, shown only when they are missing; clicking restores them |
| F10 | KILL click | State legend flips to `disarmed` (red) and becomes clickable |
| F11 | Re-arm via legend | Clicking the disarmed legend re-arms; the held ✓ still stands |
| F12 | Reflection in UI | With >=3 rejections a proposal row appears with ACCEPT; clicking persists the rule and it shows under learned rules |
| F13 | Pending survives refresh | Reload with a live decision: the card and its Confirm/Refuse return |

## H. The Electron desk app

| # | Item | Correct means |
|---|---|---|
| H1 | Launch | `electron .` boots the backend, binds :8080, prints the LAN URL and pad token, and opens the window |
| H2 | Port conflict | With :8080 already taken, the app shows a readable error and quits — it must never open a window onto a backend it did not start |
| H3 | Window loads | The window renders the same six-pane readout the browser does, at 1440x1000 on the `#0F100F` ground |
| H4 | Pad-triggered scan appears | A scan run from the pad (or any client) renders in the desk UI, not only in the tab that pressed it |
| H5 | Screenshot harness | `electron shots.mjs` drives the real app through eight states and writes real captures to `docs/images/app/` |

## G. Edge cases

| # | Item | Correct means |
|---|---|---|
| G1 | Empty-state render | Straight after a wipe every pane renders real text — no `undefined`, no blank pane, no exception |
| G2 | Bad token | `/?token=wrong` -> visible "Bad pad token" banner, panes fail closed, 401 not 500, **zero exceptions** |
| G3 | Wipe mid-flow | BUY -> WIPE -> YES must not fill against forgotten limits; `pendingVoided:true` and the balance is unmoved |
| G4 | Over-size order | Clamped to balance or refused readably; never an `STF` revert |
| G5 | Double confirm | Two confirms in a row: exactly one fill; the second says `nothing pending` |
| G6 | Concurrent confirm | Two simultaneous `yes` requests: exactly one fill, one `nothing pending` |
| G7 | Rapid market switching | Concurrent switches leave baton and the next proposal consistent |
| G8 | Kill stops the human path | While disarmed, Confirm is refused and the balance does not move |
| G9 | Malformed bodies | `/key` with no id, `/reflect/accept` with junk: 4xx or `{ok:false}`, never a 500 |

---

## Results

Run against the live product: backend on `:8080`, an anvil fork of Base mainnet
on `:8545`, a real SQLite store, real Deepgram and Claude Code calls, driven
through a real browser.

**94 of 96 items PASS. 2 are untestable for want of a credential and are marked
as such, not passed.**

- `node desktop/test/verify.mjs` — **97 pass, 0 fail**, 2 skipped, three
  consecutive runs. See "The suite finally went green" below for what had been
  keeping it red.
- `node desktop/test/loadbearing.test.mjs` — exits 0; 3 of 4 verdicts change on
  a wipe, control unchanged.
- Impeccable detector across the repository — **0 findings**.
- Browser sweep — **100/100 requests 200 OK, zero console messages** through
  scan, propose, confirm, refuse, wipe, re-teach, kill and re-arm.

| Section | Result |
|---|---|
| A. Shell and design system (16) | 16 PASS |
| H. Electron desk app (5) | 5 PASS |
| B. HTTP API (27) | 27 PASS |
| C. On-chain (11) | 11 PASS — a real mined fill on all four asset classes |
| D. Memory (7) | 7 PASS |
| E. External integrations (8) | 6 PASS, 2 UNTESTABLE |
| F. Browser UI flows (13) | 13 PASS |
| G. Edge cases (9) | 9 PASS |

**Untestable, not passed:**

- **E7 Groq.** The key is valid and lists 14 models, but every one returns
  `model_permission_blocked_project` or `_org`. That is a switch in the
  operator's Groq console, not something this repository can fix. The code tries
  the models the account actually exposes and, when they are all blocked, names
  the setting to change. Claude Code CLI is the brain meanwhile.
- **E8 1inch.** No `ONEINCH_API_KEY` exists in the environment. `ROUTE` reports
  `uniswap` and fills go direct to Uniswap V3. The 1inch path has never
  executed and is not claimed to work.

## Defects found and fixed in this run

| # | Found by | Defect | Fix | Re-verified |
|---|---|---|---|---|
| 1 | C4 | **A submitted transaction that never confirmed threw a raw viem timeout** and crashed the caller. A trading app cannot answer "did it fill?" with a stack trace. | `mined()` wraps every receipt wait, names the step and the hash, and states plainly that nothing was booked | PASS |
| 2 | B4 | **`balances()` made eight sequential RPC round trips** on every poll. Under concurrent trades this tipped the node over and `/portfolio` took 61s to fail. | All reads issued together | PASS — 61s to 4ms |
| 3 | B4 | The error path made **another RPC call before responding**, so a slow node produced an *empty* response instead of a readable one | Classify from the message; answer immediately with 503 | PASS |
| 4 | C6 | **The liquidity gate failed OPEN.** When a pool could not be quoted, `priceImpact` returned "fine" and the trade proceeded — exactly the trade the gate exists to stop. | A risk control that cannot measure now refuses, and says why | PASS — DEGEN refused at 56.4% |
| 5 | E2 | **"Buy" transcribed as "By" killed a real spoken order.** Deepgram returns the homophone often enough to matter. | "by" is accepted as the verb only when immediately followed by an amount; "by the way" and "I sat by the desk" still parse as not-orders | PASS — 7/7 cases |
| 6 | A15 | **A 503 emptied the Holdings pane silently**, which reads as "you hold nothing" rather than "we could not ask" | The node-unavailable state gets its own banner | PASS |
| 7 | A12 | The Memory pane overflowed its row by 17px, which reads as a clipped row rather than a scrolling pane | Tightened; the pane scrolls with a themed scrollbar, as the Activity log does | PASS |

**Infrastructure, diagnosed and documented rather than worked around:** the fork
kept dying mid-run. `base-rpc.publicnode.com` answers archive reads with HTTP 403
("Archive requests require a personal token") and **anvil panics on that**, so
the node died and every balance read began failing. `base.llamarpc.com` returns
525. `mainnet.base.org` serves archive but rate-limits hard. `desktop/fork.sh`
now starts the fork on the archive-capable upstream with anvil's request rate
throttled below the limit and the block pinned, and records why each alternative
fails.

## Defects found in the Electron pass

| # | Defect | Fix | Re-verified |
|---|---|---|---|
| 8 | **`start()` reported success before the port was bound.** It called `listen()` and returned, so with :8080 already taken the desk app printed its LAN URL, opened a window, and loaded *someone else's* backend — meaning the operator would confirm trades against a server they did not start. `EADDRINUSE` had no handler at all, so the error event was an uncaught exception. | `start()` awaits the bind and rejects with a readable message; Electron shows it and quits rather than opening a window it cannot back | PASS — conflict refused, clean launch binds and serves |
| 9 | **A scan run from the pad never appeared on the desk.** The server recorded it; the UI only rendered a scan the tab itself pressed — the same blind spot the Activity log had. | `GET /scan/last`, polled and rendered | PASS — the book fills in from a pad-triggered scan |
| 10 | Pane headings scrolled out of view, so a scrolling table lost the label saying what it was | Headings stick to the top of their pane | PASS |

## Defects found in the Sibyl-integration pass

Every one of these was found by running the product, not by reading it. All six
now have a check in `desktop/test/verify.mjs` section N, so they cannot come
back quietly.

| # | Defect | Fix | Re-verified |
|---|---|---|---|
| 11 | **`recall_brief` computed today's spend and then dropped it from the returned dict.** `decide()` fell back to summing "the last 10 journal events" — right today, wrong the moment a day holds more than ten trades, and silently so. | The bridge returns `spent_today`, measured over a bounded `read_events(since=local midnight)`. The window is local midnight, not UTC, so it agrees with the JS fallback instead of disagreeing by up to a day. | PASS — N1, `spent_today=125` straight from the store |
| 12 | **A closed position was never archived.** The close test was `newQty <= 1e-12`, but a round trip priced in USD never lands on exactly zero: buying $50 of ETH and selling $50 back left ~7e-7 ETH of dust, so the branch never fired. The pad went on claiming to hold 0.0000007 ETH forever, and `archived_entities` stayed empty. | Closed means *economically* nothing left — under a cent of value, or under a thousandth of what was held. | PASS — N2, a real round trip lands in the archive and the brief reports flat |
| 13 | **Selling an entire position reverted with the opaque string `STF`.** A JS double cannot hold an 18-decimal balance: `spendable()` rounded 201017173684167191602 wei to `201.0171736841672`, and parsing that back asked the router for **8398 wei more than the wallet owned**. | The swap clamps its input to the on-chain raw balance, and an `STF` is reported as what it is — the router could not pull the input — rather than as a liquidity problem. | PASS — N3, the full balance sells to the last wei, leaving 0.000000000000000000 |
| 14 | **Swaps intermittently ran out of gas.** viem sends exactly what `eth_estimateGas` returned; the swap then executes a block later against state that can cost more. One reverted at **145851 gas of a 147653 limit — 98.8% used**, no fill, gas burned. Replaying the identical call with a normal budget succeeded. | Every swap, approval and wrap estimates its own gas and adds a 30% margin. | PASS — N5, 12 consecutive swaps at 71–79% of limit, 0 failures |
| 15 | **A reverted swap reported the symptom, not the cause** — "swap mined but USDC balance did not move" — sending an operator hunting through liquidity. | A non-success receipt says the swap reverted on chain, names the hash, and says nothing was booked. | PASS — surfaced defect 14 in one run |
| 16 | **The store browser separated a heading from its rows.** Headings and rows were separate children of a two-column layout, so `archived — 1` sat at the foot of column one while its only row appeared at the head of column two, under the journal's heading. | Each tier is one block that cannot break; the journal, which may exceed a column, breaks internally but keeps its heading. | PASS — N4, and the captured screenshot |
| 17 | **A fresh fork could not trade at all.** anvil's account #0 holds no USDC in Base mainnet state, so the only quote asset the wallet ever had was whatever an earlier session left in `--state`. Round-trip a few times and it drained to dust; the next buy failed with "insufficient USDC", which reads as an app bug. | `fundOnFork` tops up the quote asset through the app's own Uniswap route, and the server does it at boot. | PASS — C0, and the boot line reports the balance |

**Two test-harness defects, which mattered as much:** one throwing section
**killed the remaining 30 checks** — each section is now guarded, so a crash is
a FAIL and the run continues. And `B7` asserted on ETH without ever selecting
it, so it depended on whichever market the *previous* run happened to end on:
it passed against a fresh store and failed on the second run against the same
one. It now names its market. Three consecutive runs against one accumulating
store: **80 passed, 0 failed** each time.

## Defects found while building the memory features

| # | Defect | Fix | Re-verified |
|---|---|---|---|
| 18 | **The pad's own refusals were never journalled.** Only the operator's NO was recorded, so the store could not answer "what did you turn down, and which rule did it", and a rule that had just vetoed a trade still looked as though it had never fired. | A REJECT verdict is journalled with the rule that caused it. A refusal an existing rule caused is not counted as evidence for mining that same rule — otherwise a rule cites its own vetoes and grows forever on nothing. | PASS — O4, O6 |
| 19 | **`POST /memory/decay {days:0}` silently became 14.** `Number(body.days) \|\| 14` treats an explicit zero as absent, so the caller was ignored and nothing was retired. | Check for a finite number, not a truthy one. | PASS — O8 |
| 20 | **The wipe diff reported a NEGATIVE loss.** It compared a snapshot taken at the wipe against the store as it stood *now*, which had since regrown — "lost -7 journal events", and tiers the wipe had certainly emptied listed as losing nothing. | The cost is settled at the moment of the wipe and stamped with the time. | PASS — O14, O16 |
| 21 | **The replay panel outlived its own evidence.** After a wipe it went on asserting "held 0.0200 ETH" directly under "I remember nothing" — and clearing it only in this tab's `wipe()` left it stale whenever the wipe came from the pad, another tab or the API. | Any wipe newer than the panel clears it, wherever the wipe came from. | PASS — visible in `11-cost.png` |
| 22 | **A dollar total was formatted as a price.** `money()` scales precision by magnitude, which is right for a $0.6458 token and wrong for a budget: "$50.000" reads as a measurement. | A separate `dollars()` for budget figures. | PASS — the replay pane reads $50 |
| 23 | **The MCP integration check talked to the server wrongly.** Piping requests in and closing stdin made the later ones race the EOF: `tools/list` answered and the `tools/call` after it was dropped, which looked exactly like a broken integration. | Hold the pipe open and wait for the answers. The MCP server also reads `SIBYL_MEMORY_DB`, not the SDK's `SIBYL_DB` — `.mcp.json` sets both. | PASS — O12, O13 |

**One more harness defect:** `B9` pressed ✓ expecting "nothing pending" without
first ensuring nothing *was* pending. A pending decision survives restarts by
design, so the check depended on whether the previous run ended mid-decision —
and a stray ✓ there would confirm a real trade, not merely fail a test. It now
clears the decision first, as `B7` now names its own market.
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

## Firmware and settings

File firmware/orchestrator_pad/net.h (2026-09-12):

#pragma once
#include <Arduino.h>
#include <WiFi.h>
#include <WiFiClientSecure.h>
#include <HTTPClient.h>
#include "config.h"
#include "settings.h"
#include "audio.h"
#include "certs.h"

// Everything the pad reads back from the xorr-pad backend in one poll. This is
// the whole model the firmware holds: it keeps no opinion of its own about what
// is armed or what is in hand, because the backend is the only thing that knows.
struct PadState {
  bool   ok        = false;   // did the poll succeed at all
  bool   armed     = false;
  bool   pending   = false;   // a decision is waiting on a ✓
  bool   chainOk   = false;
  bool   remembers = false;   // the store still has limits — false after a wipe
  String agent, market, mode, verdict;
  float  price      = 0;
  float  unrealised = 0;      // NaN-free: `hasPnl` says whether it means anything
  bool   hasPnl     = false;
  int    spentToday = -1, dayLimit = -1;
};

// GET /pad/chart — the market in hand as hourly closes, for the display pod.
struct ChartState {
  bool    ok = false;
  String  symbol, error;
  float   price = 0, change24h = 0, hi = 0, lo = 0;
  bool    hasChange = false;
  uint8_t n = 0;
  float   closes[169];
};

// Talks to the xorr-pad backend — the Mac's LAN IP over plain HTTP, or a
// Tailscale Funnel URL over HTTPS. The backend runs the gate, signs the swaps
// and does STT → brain → TTS, handing back raw 16 kHz PCM with a Content-Length
// that we stream straight to the amp as it downloads.
//
// Transport is chosen per request from the saved URL's scheme (settings.secure()):
// https → WiFiClientSecure pinned to ISRG Root X1 (certs.h); http → WiFiClient.
// When a pad token is set it rides on every request as a Bearer header.
class Net {
public:
  void begin(Settings *s) { _s = s; }
  bool wifiUp() { return WiFi.status() == WL_CONNECTED; }

  // GET /pad — one cheap poll carrying everything the LED and the caps need.
  // Deliberately does not touch the chain on the server side, so a Base hiccup
  // dims nothing here.
  bool pad(PadState &st) {
    HTTPClient http; WiFiClient plain; WiFiClientSecure tls;
    if (!beginReq(http, plain, tls, url("/pad"))) return false;
    auth(http);
    http.setTimeout(8000);
    int code = http.GET();
    if (code != 200) { http.end(); return false; }
    String b = http.getString();
    http.end();

    st.ok        = true;
    st.armed     = jsonBool(b, "armed");
    st.pending   = jsonBool(b, "pending");
    st.chainOk   = jsonBool(b, "chainOk");
    st.remembers = jsonBool(b, "remembers");
    st.agent     = jsonStr(b, "agent");
    st.market    = jsonStr(b, "market");
    st.mode      = jsonStr(b, "mode");
    st.verdict   = jsonStr(b, "verdict");
    st.price      = jsonNum(b, "price", 0);
    st.spentToday = (int)jsonNum(b, "spentToday", -1);
    st.dayLimit   = (int)jsonNum(b, "dayLimit", -1);
    st.hasPnl     = hasField(b, "unrealised") && !jsonNull(b, "unrealised");
    st.unrealised = st.hasPnl ? jsonNum(b, "unrealised", 0) : 0;
    return true;
  }

  // GET /pad/chart — flat JSON with one numeric array, parsed by hand like /pad.
  bool chart(ChartState &st) {
    HTTPClient http; WiFiClient plain; WiFiClientSecure tls;
    if (!beginReq(http, plain, tls, url("/pad/chart"))) return false;
    auth(http);
    http.setTimeout(8000);
    int code = http.GET();
    if (code != 200) { http.end(); return false; }
    String b = http.getString();
    http.end();

    st.ok        = true;
    st.symbol    = jsonStr(b, "symbol");
    st.error     = jsonStr(b, "error");
    st.price     = jsonNum(b, "price", 0);
    st.hasChange = hasField(b, "change24h") && !jsonNull(b, "change24h");
    st.change24h = st.hasChange ? jsonNum(b, "change24h", 0) : 0;
    st.hi        = jsonNum(b, "hi", 0);
    st.lo        = jsonNum(b, "lo", 0);
    st.n = 0;
    int at = b.indexOf("\"closes\":[");
    if (at >= 0) {
      const char *p = b.c_str() + at + 10;
      while (*p && *p != ']' && st.n < sizeof(st.closes) / sizeof(st.closes[0])) {
        char *end;
        float v = strtof(p, &end);
        if (end == p) break;
        st.closes[st.n++] = v;
        p = end;
        while (*p == ',' || *p == ' ') p++;
      }
    }
    return true;
  }

  // POST /key {id} — the whole deck goes through one route. `err` carries the
  // backend's own refusal so the pad can show it rather than inventing one.
  bool key(const String &id, String &err) {
    HTTPClient http; WiFiClient plain; WiFiClientSecure tls;
    if (!beginReq(http, plain, tls, url("/key"))) { err = "no route to the backend"; return false; }
    auth(http);
    http.addHeader("Content-Type", "application/json");
    http.setTimeout(45000);          // a ✓ signs and waits for a mine
    int code = http.POST(String("{\"id\":\"") + id + "\"}");
    String body = (code > 0) ? http.getString() : String();
    http.end();
    if (code != 200) { err = code > 0 ? ("backend said " + String(code)) : "no answer"; return false; }
    // 200 with ok:false is a refusal, not a failure — "disarmed", "nothing
    // pending", "not in the allowlist". Hand the words straight through.
    if (body.indexOf("\"ok\":false") >= 0) { err = jsonStr(body, "error"); return false; }
    return true;
  }

  // POST /voice (raw PCM) → stream the spoken reply to the amp. There is no
  // agent query: the backend already knows who holds the baton, and a pad that
  // second-guessed it could trade through the wrong one.
  bool talk(const int16_t *pcm, size_t samples,
            Audio &audio, String &transcript, String &reply, String &action) {
    HTTPClient http; WiFiClient plain; WiFiClientSecure tls;
    if (!beginReq(http, plain, tls, url("/voice"))) return false;
    auth(http);
    http.addHeader("Content-Type", "application/octet-stream");
    const char *keys[] = {"X-Transcript", "X-Reply", "X-Action"};
    http.collectHeaders(keys, 3);
    http.setTimeout(60000);

    int code = http.POST((uint8_t *)pcm, samples * sizeof(int16_t));
    if (code != 200) { http.end(); return false; }
    transcript = urlDec(http.header("X-Transcript"));
    reply      = urlDec(http.header("X-Reply"));
    action     = http.header("X-Action");
    streamToSpeaker(http, audio);
    http.end();
    return true;
  }

  // GET /speak?text=… → play it (connected cue, telnet `say`).
  bool speak(const String &text, Audio &audio) {
    HTTPClient http; WiFiClient plain; WiFiClientSecure tls;
    if (!beginReq(http, plain, tls, url("/speak") + "?text=" + urlEnc(text))) return false;
    auth(http);
    http.setTimeout(30000);
    int code = http.GET();
    if (code != 200) { http.end(); return false; }
    streamToSpeaker(http, audio);
    http.end();
    return true;
  }
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

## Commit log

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2026-09-07 feat(chain): real Base fork, real Uniswap fill, and the full trading loop
    P2 + P3 of PLAN.md. Closes G1 (no trading code), G7 (no fork infra) and
    G15 (no price feed).
    - chain.mjs: viem on Base. CHAIN_MODE=fork points at a local anvil fork of
    Base mainnet (real contracts, real liquidity, real signed txs, no real
    money) — this exists because 1inch and most Base liquidity have no
    testnet. mainnet mode refuses the anvil key and refuses auto-execution.
    - tokens.mjs: ETH/WETH/USDC/cbBTC/DEGEN at their Base addresses.
    - dex.mjs: quote across Uniswap V3 fee tiers, wrap/approve as needed, then
    exactInputSingle. Asserts the output balance actually moved before calling
    a swap successful. 1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
2026-09-07 feat(firmware): the deck talks to the desk app; keymap from measurement
    Closes G5 (firmware still bound to the coding-agent product) and G13.
    - agents.h rewritten for the trading deck. The grid is indexed by SCANNED
    MATRIX CELL, not cap position, because on this build they disagree: the
    columns are reversed and row 1's last key lands on matrix row 2. Those
    eight cells were measured with keytest, not guessed; r2c1 is a confirmed
    cold joint and the rest are marked UNVERIFIED until the sweep finishes.
    - net.h gains key(): POST /key {"id"}. Every press goes there and the desk
    app decides what it means, so the pad stays dumb and re-mapping never
    needs a reflash.
    - render_video.py CAP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
    [net.h, orchestrator_pad.ino]
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2026-09-07 fix(dex): check the wallet, not just memory, before signing
    Final verification caught a real one: the agent proposed a $50 buy while
    holding 13.96 USDC and the router reverted with STF. Memory says what you are
    ALLOWED to trade; the chain says what you can AFFORD, and only one of those
    was being consulted.
    - dex.spendable() reports the real balance (native ETH keeps a gas buffer).
    - swap() refuses up front with a readable error instead of an opaque revert.
    - The executor clamps an over-sized order down to the balance, so a big
    proposal degrades to a smaller real trade.
    Re-verified: BUY -> EXECUTE $50 (citing three remembered facts) -> YES ->
    fill 0xeb472dd6…, position averaged up to 0.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
2026-09-07 fix: thirteen defects found by running the product, not reading it
    Wrote TESTPLAN.md (52 items with an explicit definition of correct), then
    executed it against the live app — real backend, real Base fork, real Sibyl
    store, real Deepgram, driven through a real browser. Everything below was
    found by use.
    The serious ones:
    the kill switch did not stop the human path. KILL gated only the automated
    pass; BUY -> YES still executed. Proven with a mined fill while armed:false.
    And `armed` was a one-way latch — nothing set it back — so one press of the
    red key bricked the pad until restart. Now: yes is refused while disarmed
    (pending kept, so the same tick still stands after re-arm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
2026-09-07 feat: the pad can be taught its limits again after a wipe
    A wipe was one-way until the process restarted — nothing could put the limits
    back, so the whole memory demo could only be run once per boot. POST
    /memory/seed restores them, and the Memory pane grows a RE-TEACH button that
    appears only while the limits are actually missing.
2026-09-07 fix: six panes that fit, a ✓ that survives a refresh, and a Groq error worth reading
    Layout. Adding the book pane made five children under a grid that declared
    only two rows, so the fifth spilled into an implicit row, ate the height, and
    collapsed the other four to their headings — four panes showing nothing but a
    title. Rows are sized automatically now with a real floor and capped to the
    viewport, so panes scroll inside themselves instead of stretching the page.
    Split markets and the deck into their own pane, put the deck in five columns so
    all fifteen keys land in three rows, and cut the delisted note down to one line
    with the measurements on hover. The whole deck is now visible withou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
2026-09-07 fix: seven defects found by running the plan, and the fork that kept dying
    Wrote a 91-item test plan covering every route, every market, every strategy,
    every external call and every UI flow, each with an explicit definition of
    correct, then executed it against the running product.
    The one that matters most: the liquidity gate failed OPEN. When a pool could
    not be quoted, priceImpact returned "fine" and the swap went ahead — which is
    exactly the trade the gate exists to stop, and it failed on-chain instead. A
    risk control that cannot measure has to refuse. It now does, and says which of
    the two reasons applies.
    The rest, in the order they were found:
    A submitted transaction that never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
2026-09-08 fix: the desk app would open a window onto a backend it did not start
    Launched the Electron shell for real for the first time and found the worst
    defect in this project so far.
    start() called listen() and returned without waiting for the bind. With :8080
    already taken, the desk app reported success, printed its LAN URL and pad
    token, opened its window, and loaded the OTHER process's backend. Every key
    press and every confirmation would have gone to a server the operator did not
    start. EADDRINUSE had no handler anywhere, so the error event was an uncaught
    exception on top of that. The bind is now awaited and rejects with a readable
    message, and Electron shows it and quits rather than opening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
2026-09-08 feat: neo-brutalism in the colours the pad is actually printed in
    A photograph of the built hardware landed mid-run and corrected a binding fact:
    the case is vivid glitter-blue, not the grey tray the design system claimed,
    and the caps are white, charcoal, purple, pink and orange — not the green and
    red filament PRODUCT.md described. The palette was derived from a colour the
    object never had. Corrected from the photograph, and rebuilt to the direction
    the operator pinned: neo-brutalism, blue and white, with motion.
    Hard 3px edges, offset shadows with zero blur, black bars for pane headers,
    square everything. Three authored moments: a key that collapses its shadow and
    moves into it when pr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
2026-09-08 docs: strict audit of what Sibyl Memory is actually doing here, and 50 ideas
    Introspected the installed SDK rather than guessing at it, then confirmed every
    claim by running the real flows and watching the store change.
    The honest answer: Sibyl is genuinely used and it is load-bearing, not
    decorative. decide() is built only from recall_brief(), so deleting the store
    provably changes what the agent trades, and a test fails if the verdicts ever
    stop diverging. Eleven capabilities confirmed live, each with evidence — a fill
    writing entity:position/ETH, a refusal growing the journal, a closed position
    actually removing the entity, a spoken question answered out of FTS5.
    Nothing is faked. The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
2026-09-08 fix: seven defects the Sibyl wiring pass turned up on real fills
    Every one of these was found by running the product, not by reading it, and
    each now has a check in verify.mjs section N.
    decide() was not using the store. recall_brief computed today's spend and then
    dropped it from the returned dict, so the gate fell back to summing "the last
    10 journal events" — right today, wrong the moment a day holds more than ten
    trades, and silently so. The window is local midnight, matching the JS
    fallback rather than disagreeing with it by up to a day.
    A closed position was never archived. The close test was newQty <= 1e-12, but a
    round trip priced in USD never lands on exactly zero: $50 of ETH in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
2026-09-08 fix: seventeen defects found by driving the app in a real browser
    Every route, every key, every control, plus the edge cases a careless user
    actually produces: empty and malformed bodies, a bad token, double-clicking
    confirm, refreshing mid-decision, resubmitting after success, selling what is
    not held, the chain node dying mid-session, and three viewport sizes. Zero
    console errors and zero failed requests in any state.
    The two that mattered most were both the same failure — claiming something is
    true when it is not.
    POST /voice invented an answer out of silence. An empty body, and a second of
    pure silence, came back with x-transcript:"" and a confident spoken portfolio
    summary, having s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
2026-09-08 fix: four defects the second browser audit found on the new desk
    The first audit was run against the neo-brutalist interface. That interface was
    replaced entirely, so every flow and edge case was driven again through Chrome
    against the new one — and four things were wrong.
    The kill note promised something the kill switch does not do. It said "the
    decision is kept so re-arming honours it", but stopping voids the decision on
    the table, exactly as POST /panic always has, so a ✓ afterwards answered
    "nothing pending" instead of the refusal the words had promised. The code is
    right — a loaded ✓ left behind a kill switch is what bites — so the copy now
    says what stopping does, and names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
2026-09-08 fix: the suite goes green — two of the three failures were mine, not the RPC
    For most of this work the suite reported 74 pass and 3 fail, and I attributed
    all three to a free public RPC stalling. Two of them were my own defects, and
    the systematic pass surfaced them the moment the node had an easy run.
    The fork wallet drained mid-session and never refilled. fundOnFork only runs at
    boot, so an app left running through a long demo eventually answers every buy
    with "insufficient USDC: need 25, have 0.000034" — which reads as a broken
    product and is really a sandbox out of pretend money. Every check after that
    point then failed for want of money, not want of a node. The execute path now
    top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
2026-09-08 feat(pad): the backend the physical pad talks to, and the ticker bug it found
    GET /pad is one cheap poll carrying everything the ESP32's status light and
    keycaps need — armed, who holds the baton, what is in hand, whether a decision
    waits on a ✓, whether the store still remembers anything, the day's spend
    against the limit, and unrealised P&L against remembered entry prices. It
    deliberately touches neither the chain nor a swap quote: prices come from the
    cached candle feed, so a Base hiccup cannot dim the light on the desk. 0.9 ms
    warm, and it answers 200 with chainOk:false while /portfolio correctly 503s.
    GET /speak?text= gives the pad a voice. Raw 16 kHz PCM at the same rate the mic
    r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
2026-09-08 docs: rewrite PLAN.md against the code and live credentials, 2026-09-09
    Seven phases from where it is to done, every task tagged and named with the
    file it touches, plus ten gaps tied to the task each one blocks.
    Three findings correct things previously recorded. The route label lies: ROUTE
    reports 1inch whenever ONEINCH_API_KEY is set while swap() only ever calls
    Uniswap V3, and there is no 1inch call anywhere in main/. The Groq key is
    invalid rather than permission-blocked — a live probe returns invalid_api_key.
    And there is no separate xorr-desktop project: the Electron app is
    xorr-pad/desktop, it is not packaged, and it does not manage anvil.
    Also recorded so they are not re-opened: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
2026-09-08 fix: the route a fill reports is now the route it took
    ROUTE branched on ONEINCH_API_KEY while swap() only ever called Uniswap V3,
    so setting a key nothing reads made every fill claim a 1inch route it had
    not taken. A fill's route is now read back off the mined receipt's `to`.
    Also in this pass:
    - firmware: xorr-pad/firmware was a half-migrated copy calling POST /select,
    which its own backend answers 404. Merged the rewrite in, keeping this
    copy's newer keytest (guided MAP mode) and its wiring tables, which the
    rewrite had dropped. Compiles for the S3 at 38% of app space.
    - the test suite was manipulating a database nothing else used. It guessed
    /tmp/xorrpad-server.db while the se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
    [net.h, orchestrator_pad.ino]
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2026-09-08 refactor: a router seam, so an aggregator is a file rather than surgery
    main/routers/ splits out the two things that differ between venues — quote()
    and buildSwap(). Everything around them stays in dex.mjs: the balance clamp,
    the allowance, the gas margin, waiting for the receipt and checking the
    balance actually moved. That is where the expensive bugs were and duplicating
    it per router would re-introduce them.
    pick() refuses to silently fall back. Naming a router that cannot run is an
    error, because quietly routing somewhere else is how a fill ends up claiming
    a venue it never touched.
    The move broke one thing and the suite caught it: the extracted addr() lost
    the native-ETH-to-WETH map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
2026-09-08 feat: the tokenized equities are priced, from their own pools, on a fork
    The plan assumed this was impossible here. It is not, and the reason is the
    interesting part: a B20 token is implemented by the Base node and reverts on
    a fork, but the POOL behind it is ordinary EVM bytecode — an EIP-1167 clone,
    45 bytes — so slot0() answers normally. Price the pool and never touch the
    token, and a fork quotes an equity it can never trade.
    All ten pool addresses were discovered on-chain rather than copied from a
    listing: getPool(USDC, token, 10) against the CL factory at
    0xf8f2eB4940CFE7d13603DDDD87f123820Fc061Ef. Ten of ten price in 29ms and the
    Markets screen shows them beside the refusal that s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
2026-09-08 feat: a QR to provision the pad, written from scratch and actually verified
    Provisioning means typing the desk's LAN address and the pad token into a
    captive portal on a phone keyboard, while the phone is joined to the pad's own
    access point. That is where a demo dies. "Connect the pad" in the rail now
    shows a scannable code; it is on demand rather than always, because it carries
    the token and the desk is often on a visible screen.
    The encoder is written here rather than fetched from a CDN: the desk has to
    work on venue wi-fi, and a QR library that fails to load is a QR missing
    exactly when it is needed.
    It was wrong three times and only a real decoder caught it. The first version
    placed c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
2026-09-09 fix: numbers and panels the operator is asked to trust
    Four faults found by working through the app in a browser.
    The entry price in a verdict's reasons was Math.round()ed, so AERO at $0.6154
    was cited as "@ $1" and anything under fifty cents as "@ $0" — in the very
    sentence the decision rests on. Three of the six markets trade under a
    dollar. Now formatted at the precision it was paid at, and asserted across
    the range from VIRTUAL at $0.04 to cbBTC at $78,723.
    The market in hand was this tab's opinion, not the backend's. /markets is
    fetched once and activeMarket only ever changed on a click here, so a market
    chosen on the physical pad — the entire point of the pad — never reached th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
2026-09-09 fix: a mis-heard ticker can no longer become the market in hand
    Spoken "Buy fifty dollars of Zorblax", Deepgram returned "Buy $50 Absorb
    Locks." — no preposition, no alias match — and the pad proposed BUY $50 of
    ETH, the market that happened to be in hand. Trading a different asset from a
    word it did not recognise is the worst failure this product has, and it is
    the exact bug the "ETA" case was supposed to have closed.
    The old guard only fired when the transcript contained "of|in|into" before
    the unknown name. The transcriber does not reliably produce one. It now works
    from what is LEFT after the verb, the amount and the filler words: anything
    still standing was meant to name a market,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
2026-09-09 fix: a dead backend no longer looks like a healthy one
    With the backend killed mid-session the desk carried on showing $13,701, a
    block number and a wallet address, all minutes stale and presented as
    current, with nothing to say it had lost its backend. refresh() returned
    early on a failed health poll and left the previous render standing. On a
    trading desk that is worse than showing nothing, because the operator can act
    on it.
    It now says so — "Nothing on this screen is live, the figures below are the
    last ones it managed to read" — blanks the total, the block and the wallet,
    and takes precedence over the node-down banner, since without the backend the
    app cannot even tell whether the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
2026-09-09 docs: BROWSERPLAN.md — 61 items, all passing, and the 14 defects the run found
    The plan was written before testing, from the code, so nothing in it is
    shaped by what happened to pass. Every item was executed against the packaged
    app in a real browser, every failure fixed at the root, and the whole plan
    re-run afterwards. Records that Claude in Chrome could not deliver synthetic
    input in this environment — no event reaches the page at all after navigate,
    while the same click in the in-app browser works — so the run was completed
    there.
2026-09-09 fix: the test report and the docs both said things that were no longer true
    Two SKIP lines in the suite were printed unconditionally — they measured
    nothing — and the footer ended with a hardcoded "(2 skipped: credentials
    unavailable)" that stayed true only by coincidence. One of them still claimed
    "no ONEINCH_API_KEY; route falls back to Uniswap V3", written before an
    aggregator existed. A line in a test report that cannot disagree with reality
    is the same defect as a route label that cannot disagree with the receipt.
    E4 now actually calls Groq and reports what it gets back
    (model_permission_blocked_project — account-level, not a code fault). E5
    became a real check and passes: an agg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
2026-09-09 docs: rewrite PLAN.md against a fresh audit of the code
    The previous plan predated the aggregator, best execution, read-only mainnet
    and the two QA passes, and still recorded "1inch / any aggregator: not
    implemented, ROUTE is a label only" as the current state.
    Re-derived from the code rather than from the older plan: 32 tasks across six
    phases, 11 gaps, each tied to the task it blocks. The audit turned up three
    things the docs did not have — seven Memory methods with zero call sites,
    archived positions that are stored and never displayed, and SIBYL-AUDIT.md
    listing six capabilities as MISSING that now ship.
    Planning only; no code touched.
2026-09-09 feat: the archive is reachable, rule status is Sibyl's, dead surface is gone
    Phase 3 of PLAN.md — the places the Sibyl integration was thinner than the
    code deserved.
    The agent archives a closed position rather than deleting it, but
    archived_entities is a separate table and is NOT in Sibyl's FTS index, so
    searching the tiers for "AERO" found the journal and the baton and missed the
    one row that says what was held and what it closed at. Asked "have I ever
    held AERO?" with nothing open, it answered "no record" while holding exactly
    that record. The spoken brain now reads the archive directly, matching on the
    question's own words rather than the alias table — a position whose symbol is
    no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
2026-09-12 feat(cad): a 2.4" display pod, and one pod per screen
    part_display.py now builds a pod for every entry in MODULES. The first is the
    1.54" ST7789; the second is the 2.4" ILI9341 UNO shield (listed PCB 72.20 x
    52.7, active area 48.96 x 36.72), laid back to 50 degrees because it gets
    touched.
    The window is always centred on the pad. The shield's panel sits about 3.6 mm
    off its PCB centre, away from the reset button, so the PCB pocket moves
    instead and reaches x -42.0, 1.0 inside the side wall. The band scheme is no
    longer mirrored for that reason. Both pods gain a 45-degree bevel on the
    window's outer edge and four recesses for rubber feet, so a press doesn't
    slide the pod.
    audit_display.py c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
    [display-coupon-24.stl, display-coupon.stl, display-pod-24.stl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]
2026-09-12 feat(cad): close the display pods' backs, and give the wires an exit
    Each pod now has a back cover: a 2.0 plate recessed 3.0 into the back, so it
    clears the R8 back corners, held by four M2.5 x 6 self-tappers (the speaker's
    hardware) in square-pilot bosses top and bottom at X +-35.5. It prints flat.
    Closing the back meant the headers and their connectors could no longer leave
    through it. On the 2.4" shield they reach Y 108 where the back used to be at
    88.6, so each pod's depth is now derived: far enough back that its connectors
    end 1.0 in front of the cover and clear of the bosses. The 2.4" pod is 75.0
    deep, the 1.54" 55.4 — the latter pushed out a further 2.0 when the audit
    caught its to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
    [display-cover-24.stl, display-cover.stl, display-pod-24.stl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]
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2026-09-12 feat(cad): 2.8" SPI display pod, printed upright with supports on one P1S plate
    - tft28_spi pod from LCDwiki's MSP2807 outline drawing: the 86 x 50 PCB laid
    landscape behind 1.6 side walls, the window on the off-centre active area
    (clear of the touch viewing area, glass only), the 14-pin header row beside
    the right-wall cable opening with the side tongue stepped around it
    - bodies print upright with per-object tree supports (on a side wall the whole
    upper wall hung over the cavity); the cap lies 20 to the body's left, clear
    of its supports; each 3MF object centred and placed by its build item; plates
    on filament 1 (the CLI crashes slicing filament 2)
    - slice_bambu.py resolves the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
    [display-cap-24.stl, display-cap-28.stl, display-coupon-28.stl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]
2026-09-12 feat(firmware): drive the 2.8" ILI9341 display pod (320x240, landscape)
    - display.h: Adafruit_ILI9341 on FSPI — SCK 39, MOSI 40, DC 41, RESET 42,
    CS 1, LED 2 at 20 MHz — with the price, 24h move and 48h chart laid out
    for 320x240 on a PSRAM canvas, and a boot test card: palette bars, a
    border on the panel's edge, an arrow that must point up the slant
    - telnet: `screen` reports what the display last drew; `testcard`; `rot 1|3`
    - each chart fetch logs its result; SDO and the touch pins stay unwired
    - README: the 2.8" wiring and library, which USB-C port carries the log,
    and to check the port is the pad's before uploading
    [orchestrator_pad.ino]
2026-09-12 feat(cad): one-filament keycap reprint — outlined symbols, no supports
    - part_caps "outline" legend style: a bold mark (BUY, SELL, BASE, RISK,
    PORTFOLIO) is cut as a 0.9 outline with its middle standing; a thin mark,
    or a middle too small to read (an X's crossing), is cut as a single line
    - export_caps_plate.py: every cap but MIC, upside down on its top face in its
    pad position 26 apart, filament 1, supports off — checked: widest cut 2.58
    (a short bridge), no groove under 0.8, no wall under 0.6, wall lean 7.4 deg
    - glyphs: RISK's bar stops 0.9 above its dot, YIELD's rings sit 0.75 off the
    slash, so both gaps print; colour-infill exports regenerated to match
    - slice_bambu: a pla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
    [caps-plate.3mf, caps-plate.stl, caps-white.stl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]
